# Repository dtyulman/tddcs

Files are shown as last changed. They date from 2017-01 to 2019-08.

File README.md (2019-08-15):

# Time-domain diffuse correlation spectroscopy (TD-DCS)

Danil Tyulmankov, MIT M.Eng. Thesis

Code for analysis and modeling, and Latex source.

Thesis: 
https://dspace.mit.edu/handle/1721.1/113444

Associated publications: 
1) https://doi.org/10.1364/OPTICA.3.001006
2) https://doi.org/10.1364/OL.43.002756

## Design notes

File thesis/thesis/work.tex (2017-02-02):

%% !TeX root = work.tex
%\documentclass[thesis.tex]{subfiles}
%\usepackage{xr-hyper} 
%\externaldocument{intro}
%\begin{document}

\chapter{Completed Work} \label{sec:Chapter2}

Having set the theoretical ground for time-domain diffuse correlation spectroscopy and alluded to some of the instrumentation, as well as experimental and computational techniques involved in estimating optical and dynamical properties of turbid media, we now discuss in detail the prototype construction, the initial measurements, and theoretical modeling that was done over the course of this project. These are clearly only the first steps and there is much more development to be done and theory to be explored. 

\section{Instrument prototype construction} \label{sec:prototype_construction}
The primary challenge in meeting the conflicting narrow-pulse-width and long-coherence requirements of TD-DCS is in constructing the laser source and detector hardware. A practical requirement for making measurements is to have a high photon flux, so a custom source laser with high peak power must be designed, and sensitive time-correlated single photon counting detectors must be used. 

The final system design is shown in \autoref{fig:TD-DCS_instrument}. For this thesis work, only a subset of the system was implemented to demonstrate proof-of-concept, which we refer to as "first generation," and used for initial measurements. The "second generation" system was used in subsequent data collection for the theoretical discussion in \autoref{sec:theory}.

\subsubsection{First generation}
The source laser is a distributed Bragg reflector (DBR) laser (PH852DBR280TS, Photodigm, Inc.), with nominal light wavelength of 852 nanometers, continuous-wave coherence of 10 meters and 180 milliwatt average optical power (480 mW peak power). The pulses are created by electrically gain-switching the seed laser using a commercial picosecond pulsed laser driver (T165-9, Highland Technology, Inc.). Although the maximum repetition rate at which the TPSFs (4-5 ns long) from consecutive pulses will not overlap is 200MHz, the pulse board repetition rate is variable and we used it at no more that 150MHz. The pulse board also specifies that it is possible to vary the pulse width by injecting current pulses of varying width into the laser, but we found that the pulse width could not be increased beyond 100ps without corrupting the pulse shape, likely due to the physical limitations of the laser. 

\begin{figure}[tb]
    \begin{subfigure}[t]{0.49\textwidth}
        \centering
        \raisebox{0.75in}{}
        \caption{}
        \label{fig:laser_package}
    \end{subfigure}~%
    \begin{subfigure}[t]{0.49\textwidth}
        \centering
        
        \caption{}
        \label{fig:pulse_board}
    \end{subfigure}
    \caption{(a) Photodigm Mercury TOSA package (b) Highland T165 pulse board with connected Type-1 butterfly-packaged laser.}
\end{figure}

The primary challenge here is controlling the laser with the pulse board. The laser comes in a Mercury TOSA package (\autoref{fig:laser_package}) where due to the length of the ribbon cable, there is an excess parasitic inductance. While this is not an issue in the CW operation for which it was designed, for our pulsed operation the cable must be removed and the laser pins connected directly to the pulse board. Furthermore, the pulse board connector is designed with a pin socket connection for a Type-1 butterfly-packaged
laser diode (\autoref{fig:pulse_board}) that is incompatible with our laser. As such, the pin sockets must be removed and the laser pins soldered directly to the copper pads to which the pin sockets were attached. To account for the mismatch in pin spacing as shown in \autoref{fig:laser_board}, the gap is simply filled with solder -- an inelegant but effective solution.
%\TODO{controlling the pulse board}

\begin{figure}[tb]
    \begin{subfigure}{0.49\textwidth}
        \centering
        
    \end{subfigure}~%
    \begin{subfigure}{0.49\textwidth}
        \centering
        
    \end{subfigure}
    \caption{SolidWorks model of the laser and pulse board connection. Copper pads represent electronic connections to the pulse board. For both the board and the laser, the cathode is shown in red and the anode in blue. Original files can be found at \coderepolink}
    \label{fig:laser_board}
\end{figure}

The second challenge in the construction of the custom system is effectively coupling the light into the medium. The laser is mounted onto a custom machined aluminum frame as shown in \autoref{fig:laser_assembly}. The frame serves both as a heatsink and as an adapter for off-the shelf hardware used to for further shaping the laser beam. First, to avoid backreflections that may damage the laser, it is necessary to install an optical isolator at the output of the laser. For the 852nm wavelength of our laser, we used Thorlabs model IO-3D-850-VLP. To accurately position the isolator into the beam's path we mounted the isolator onto a Cage XY Translator (Thorlabs CXY-1) which was centered on the custom laser frame using 6mm diameter aluminum rods (Thorlabs ER4) as shown. Finally, to couple the light into an optical fiber for delivery into the medium, we used an adjustable FiberPort (Thorlabs PAF-X-15-PC-B). To mount the FiberPort onto our cage setup we used another XY translator which we modified with four screw holes to attach the FiberPort directly to the translating component. The FiberPort then offers an FC connection to an optical fiber. For our experiments, as with DCS, light is delivered to the medium using a multimode fiber. %, in our case 62.5 micron graded-index Thorlabs model \TODO{find model}.  

\begin{figure}[tb]
    \begin{subfigure}{0.49\textwidth}
        \centering
        
    \end{subfigure}~%
    \begin{subfigure}{0.49\textwidth}
        \centering
        
    \end{subfigure}
    \caption{SolidWorks model of the custom pulsed laser assembly. In the final construction, the assembly is bolted to a monolithic heatsink (not shown). Original files can be found at \coderepolink}
    \label{fig:laser_assembly}
\end{figure}

On the detection side, as with the other photon correlation techniques, to maximize $\beta$ and therefore the SNR, we would like to limit the detection area to a single speckle. In practice, this is not achievable so, as with DCS \cite[Section 6.2]{Boas1996thesis}, we instead use a single-mode fiber to collect scattered light from the medium and deliver it to the detector. For our experiments, 5.6 micrometer single-mode silica fibers are used. The detector is a novel red-enhanced, single-photon avalanche diode detector (SPAD), with a high temporal resolution, from the SPADlab at the Politecnico de Milano \cite{Gulinatti2012,Giudice2012}. 

Although a custom time-to-digital converter (TDC) card is included in the final design, for the first-generation prototype we use an off-the-shelf Becker \& Hickl GmbH SPC\=/600 \cite{Becker2014} card to record the micro and macro photon arrival times. Although it was originally designed for fluorescence correlation spectroscopy \cite{Becker2005, Becker2014}, the data collection technique is identical\footnote{The signal for FCS, of course, is different -- the source of light is fluorescent markers on molecules}. The photon arrival data was then exported from the Becker \& Hickl software for offline data analysis (\autoref{sec:analysis}).

\subsubsection{Second generation}
Since the construction of the original prototype, the second-stage amplification was added to the laser source using a pumped taper diode amplifier (m2k-TA-0850-3000-DHP, m2k-laser GmbH), allowing much higher peak power to be used in experiments \cite{Kangara2014,Poelker1995}. Furthermore, the development of the custom data acquisition hardware was completed, incorporating the time-to-digital converter (TDC) card with the custom FPGA firmware to measure photon timing, and a USB3 interface (Cypress EZ-USB FX3) to transfer photon data to the computer. Furthermore, an alternative pulsed laser source was acquired (PicoQuant CPDL-S-760) with a nominal wavelength of 760nm, used in the experiments for \autoref{sec:theory}.

\begin{figure}[tb]
    \centering
    
    \caption{Schematic of the TD-DCS instrumentation. Reprinted from \cite{Sutin2016}.}
    \label{fig:TD-DCS_instrument}
\end{figure}

\section{Data analysis methods} \label{sec:analysis}

\subsection{Computing the temporal point spread function}

As discussed in the previous section, we use time-correlated single photon counting methods to record the \emph{micro} and \emph{macro} times of the photons. To compute the TPSF, we can use the exact approach discussed in \autoref{sec:TD-NIRS} and simply histogram the micro times (i.e. time-of-flight) for many photons to estimate the distribution of intensity over time. There are, however, several instrumentation-specific considerations to be addressed.

\subsubsection{Reversed start-stop}
Many TCSPC modules, including the Becker \& Hickl SPC\=/600 and our custom time-to-digital converter, operate in what is known as "reversed start-stop" mode. In this setup, rather than recording the time starting at the generation of the input laser pulse and stopping at the arrival of a photon, the "stopwatch" starts running at the arrival time of a photon, and stops at the generation of the next laser pulse. The advantage of this method is that since photons are typically detected at a much lower rate than the input pulse train (i.e. there is less than one photon detected on average from each laser pulse), we only need to operate the hardware at the photon detection rate, rather than the much higher laser pulse rate \cite{Becker2014}. This is easy to compensate for by simply reversing the time axis of the histogrammed TPSF. 

\subsubsection{Folding}
When recording signals with very high repetition rates it may be necessary to record the TPSF over several periods of the pulsed laser. That is, instead of using every laser pulse as the time-of-flight reference, we might use every other one, or every fourth, and so on. The Becker \& Hickl SPC\=/600 card allows frequency division values of $d = 1,2,4,8, \textnormal{or } 16$. Of course, we can only work with a single TPSF. One option is to pick one period of the recorded histogram and delete all of the other photons. This is clearly unfavorable since we are only using $1/d$ of the recorded photons for analysis and thus unnecessarily reducing the signal-to-noise ratio. A much better approach is to fold all of the histograms onto one, as shown in \autoref{fig:tpsf_folding}

\begin{figure}[tb]
    \centering
    \begin{subfigure}{\textwidth}
        
    \end{subfigure}    
    \begin{subfigure}{\textwidth}
        
    \end{subfigure}
    \caption{TPSF folding. Top plot shows an example of a time-of-flight histogram collected using a Becker \& Hickl SPC\=/600 card with the frequency divider set to 8 (the eighth peak is out of range and therefore not recorded). Bottom left shows all the individual peaks shifted to line up with the first (each peak shown in its own color). Bottom right shows the sum of all the peaks to create the final TPSF (note the decrease in noise and the y-scale).}
    \label{fig:tpsf_folding}
\end{figure}

We would like to simply shift the $k$\textsuperscript{th} additional "sub-TPSF" to the left by $kT$ where $T$ is the time between two consecutive pulses. In reality, however, the micro time is discretized: in \autoref{fig:tpsf_folding}, for instance, we have 4096 discrete time bins spanning 50ns. Since the repetition rate of the laser $T$ (e.g. $\frac{1}{100\textnormal{MHz}}$) is typically not an integer multiple of the time resolution of the micro time (e.g. $\frac{50\textnormal{ns}}{4096}$), a more careful folding procedure is necessary. We compute the autocorrelation function of the raw histogrammed signal. The peaks in the autocorrelation function then will correspond to the lags of the raw signal for which it is most similar with itself. Since all of the TPSFs in the raw signal should be identical, the lag values for the autocorrelation peaks are the precise values by which we should shift each "sub-TPSF" for the best overlap with the first "sub-TPSF." We can then subtract the shifts from the raw stored micro times accordingly. The implementation to perform the folding directly on the TPSF is provided in \autoref{code:fold_tpsf} and on the raw micro times in \autoref{code:fold_micro}.

\subsection{Estimating $\mu_a$ and $\mu_s'$} \label{sec:est_opt_params}
One of the advantages of TD-DCS is the capability of estimating the tissue optical parameters concurrently with the measurements of the dynamical properties. Having computed the temporal point spread function as in the previous section, we can then analyze it using all of the computational tools developed for TD-NIRS \cite{Torricelli2014}. Although this aspect is outside of the scope of this thesis, we include a brief discussion for completeness. 

As mentioned in \autoref{sec:TD-NIRS}, the measured TPSF is actually not the true impulse response of the system. It is a convolution of the pathlength distribution function of the medium (i.e. the "true" impulse response of the medium) with the impulse response function (IRF) of the laser source and detection system. The resulting measured TPSF is therefore a broadened version of the true TPSF. In TD-NIRS, the laser pulses are a few picoseconds wide, and compared to the width of the "true" TPSF are negligible, so it is valid to ignore the broadening effects due to the instrumentation. Thus, we can directly fit the measured TPSF to estimate $\mu_a$ and $\mu_s'$. However, due to the coherence length requirements of DCS, we must use wider pulses that are hundreds of picoseconds and are no longer negligible compared to the width of the "true" TPSF, so fitting the measured TPSF directly will result in an error that is an increasing function of the pulse width. 

To compensate for this broadening, there are several deconvolution algorithms that attempt to remove the broadening effects of the instrumentation IRF. Deconvolution, however, is in general an ill-posed inverse problem that does not have a unique solution. Solving ill-posed problems can be considered an entire field in itself, and we do not discuss it further. See \cite[ch. 20]{Handbook} for discussion of this issue in the context of TD-NIRS. An alternative approach may be to pre-convolve the theoretical TPSF with the measured IRF before fitting. In this approach, rather than attempting to remove the effects of the IRF from the measured TPSF, we are fitting to the data a function that already has the IRF factored into it. 

\subsection{Computing the autocorrelation function} \label{sec:acf_comp}
As discussed in \autoref{sec:Coherent}, to estimate the dynamic properties of the medium, we measure the time-averaged autocorrelation function of the scattered light intensity $g_2(\tau) = \frac{\expval{I(0)I(\tau)}} {\expval{I(0)}}$ and find the parameters of the appropriate model to best fit the measured data. In this section we discuss the algorithms to compute this function from the photon-counting data. Since the intensity autocorrelation is equal to the photon autocorrelation, we will use $I(t)$ to denote the photon stream.

\subsubsection{Direct summation}
In general, by definition, the autocorrelation function $R(\cdot)$ of an arbitrary discrete-time signal $f(\cdot)$ is given by the convolution
\begin{equation} \label{eq:acor_def}
R(\tau) = (f*\bar{f})(\tau) 
        \equiv \sum_{t\in\mathbb{Z}}f(t)\bar{f}(t-\tau) 
        = \sum_{t\in\mathbb{Z}}f(t)f(t+\tau) 
\end{equation}
where $\bar{f}(t) = f(-t)$.

Using this definition, given the intensity of the photon stream as a function of time, we can directly evaluate this sum for every value of $\tau$. This procedure, however, is time-consuming since only the photon arrival times are recorded and therefore must be converted to a temporal-raster form. For a measurement $L$ seconds long at a sampling frequency $\omega_s$, this is a vector of length $T = L\omega_s$, containing a 1 if a photon arrived within that time bin and 0 otherwise, (e.g. if the vector of photon "macro" times is $\vb{m} = (1,4,5,7)$, then $I(t) = (1,0,0,1,1,0,1)$, see \autoref{code:times_to_bins}). 

Since $I$ is a finite-length vector (or alternatively, we can consider it to be a discrete-time function that is equal to zero outside of the interval $[0,T]$), it only makes sense to compute $R(\tau)$ for $\tau \leq T$, since $R(\tau) = 0$ for $\tau > T$. Furthermore, we are not interested in lags beyond which the signal has fully decorrelated, so we only need to consider $\tau \leq \tau_{max}$. In our application, $\tau_{max} << T$. Thus, the computational complexity of this algorithm is $\Theta(T\cdot\tau_{max})$ since we are summing $T$ terms $\tau_{max}$ times. 

Finally, note that computing the autocorrelation of the intensity $I(t)$ according to \autoref{eq:acor_def} results in the \emph{unnormalized} autocorrelation $G_2(\tau)$. Normalizing, we get 
\begin{equation}
g_2(\tau) = \frac{T}{N^2}G_2(\tau) 
\end{equation}
where $N$ is the total number of photons collected and $T$ is the number of time bins as defined above, so $G_2(0) = \frac{N^2}{T}$

\subsubsection{Fast Fourier transform}
Since the convolution of two signals in the time-domain is equivalent to their multiplication in the Fourier domain \cite{OW1997}, given an arbitrary function $f(t)$ we can instead compute $F(k)$, its discrete Fourier transform (DFT) (note that this is the discrete analog of \autoref{eq:fourier})
\begin{equation}
F(k) = \mathcal{F}\{f\} \equiv \sum_{t=0}^{T-1}f(t)e^{-\frac{2\pi j kt}{T}}, ~k\in\mathbb{Z}
\end{equation}
and compute the autocorrelation by
\begin{equation} \label{eq:acor_fft}
R(\tau) = \mathcal{F}^{-1}\left\lbrace \mathcal{F}\{f\} \cdot \mathcal{F}\{\bar{f}\} \right\rbrace
\end{equation}
where the inverse DFT is given by
\begin{equation}
\mathcal{F}^{-1} \{F\} \equiv \sum_{t=0}^{T-1}F(k)e^{+\frac{2\pi j kt}{T}}, ~k\in\mathbb{Z}
\end{equation}

The fast Fourier transform (FFT) algorithm allows us to compute the DFT as well as the inverse DFT with computational complexity $\Theta(T\log T)$. The element-wise multiplication in the Fourier domain takes $\Theta(T)$ time, so the entire algorithm has computational complexity $\Theta(T\log T)$ \cite[ch. 30]{CLRS2009}. Note that this method does not allow us to specify the longest lag we are interested in $\tau_{max}$ and computes the autocorrelation for all of the values of $\tau$ such that $f(t)$ and $f(t+\tau)$ overlap. In other words, $\tau_{max}=T$. As before, letting $f(t)=I(t)$ in \autoref{eq:acor_fft} gives us $G_2(\tau)$ so to compute $g_2(\tau)$ normalization is done as in the previous section. 

\subsubsection{Histogrammed interarrival times}
A much faster method for our application operates directly on the photon arrival times. To see the equivalence of this method with the direct summation method described above, consider \autoref{eq:acor_def}. First, observe that in our application, $f(t) = 0~\textnormal{or}~1~\forall t$, so if $R(\tau) = k$ for some $\tau$, then there were exactly $k$ pairs of photons arriving $\tau$ time steps apart. Therefore, for every value of $\tau$ we are interested in, we would like to count all pairs of photons that are $\tau$ time steps apart. The algorithm is outlined as follows.

Suppose we have recorded a length-$N$ vector $\vb{m}$ of photon arrival times (i.e. "macro" times). We initialize a length-$\tau_{max}$ array of zeros $R$ that we will use to histogram the interarrival times of the photon pairs.

The $i^{th}$ iteration of the algorithm considers entry $m_i$ in $\vb{m}$ as the first photon of a pair. It then, one by one, looks at all the subsequent photons $m_j,~(j>i)$ and calculates $m_j-m_i$, the interarrival time of the photon pair. Suppose $m_j-m_i=\tau$, so we increment $R(\tau) \leftarrow R(\tau) + 1$. Once we reach an entry $m_{j^*}$ such that $m_{j^*}-m_i>\tau_{max}$, we stop this iteration since $\vb{m}$ is a strictly increasing sequence and we know $m_{k}-m_i>\tau_{max}$ for all $k>j^*$. We increment $i$ and begin the next iteration. We iterate until $i = N$ and all the photon pairs that are less than $\tau_{max}$ seconds apart have been considered.

%% Although this works (and might be more intuitive) this is not quite right and is actually slower since we're performing unnecessary computations and discarding values %%
%For a length-$N$ vector $\vb{m}$ of photon arrival times (i.e. "macro" times), we begin by computing the first difference $\vb{m^{(1)}}$, i.e. $m^{(1)}_i=m_{i+1}-m_i$. Note that since $\vb{m}$ is strictly increasing, all entries in $\vb{m^{(1)}}$ are positive. Next, we histogram the entries in $\vb{m^{(1)}}$ into the vector $R$ so that $R(\tau)$ contains the number of occurrences of $\tau$ in $\vb{m^{(1)}}$, in other words, the number of \emph{consecutive} photons in $\vb{m}$ that are $\tau$ apart. Since we are not concerned with lags greater than $\tau_{max}$, discard all entries $m^{(1)}_i > \tau_{max}$. 
%
%There might, however, exist non-consecutive photons that are $\tau$ apart (e.g. if $\vb{m} = (1,4,5,7)$, the first and second entries are $\tau=3$ time steps apart, as well as the second and fourth). So, we next compute the difference in arrival times of every other photon $\vb{m^{(2)}}$, i.e. $m^{(2)}_i=m_{i+2}-m_i$. Histogram and add these values into $R$, so that $R(\tau)$ now contains the number of occurrences of $\tau$ in both $\vb{m^{(1)}}$ and in $\vb{m^{(2)}}$. Again, discard all entries $m^{(2)}_i > \tau_{max}$. Continue this procedure until $m^{(k)}_i > \tau_{max}~\forall i$.

If we were interested in computing the longest possible lag (i.e. $\tau_{max} = T$), we would have to consider all pairs of photons, so the worst-case computational complexity is $O(N^2)$. Note that this is a function of the number of photons $N$, rather than the time of the experiment $T$. Since we are only interested in lags $\tau \leq \tau_{max}$, the complexity is actually much better since each iteration only looks at photons that arrived less than $\tau_{max}$ seconds after the one under consideration for that iteration. If the average flux is $\phi$ photons per time step, the expected number of pairs of photons considered in each iteration is $\phi\tau_{max}$ (note $\phi T=N$). Therefore, in expectation the runtime is $\Theta(N\cdot\phi\tau_{max})$

What we have computed in the vector $R$ is, in fact, the unnormalized measured intensity autocorrelation function $G_2(\tau)$. Once again, we normalize these values as before to compute $g_2(\tau)$. See \autoref{code:acorr_times} for an implementation of this algorithm. 

\subsubsection{Progressive binning/Multiple tau} 
For completeness, we include an alternative fast method for computing the autocorrelation function, as used in the Becker \& Hickl photon counting software, \cite{Becker2014} as it is representative of the ideas used in many of the current digital correlators. 

We begin by computing the autocorrelation as in \ref{eq:acor_def}. In other words,  after converting the photon arrival times to the temporal-raster form, we shift our signal to get $I(t+\tau)$, element-wise multiply $I(t)$ and $I(t+\tau)$, and sum all the values in the resulting vector. After $k_\tau$ shifts (where $k_\tau$ is a user-defined parameter), we re-bin the photon-arrival raster by a factor of three: for every three time bins of length $l$ we replace it with a single time bin of length $3l$, and if a photon arrived in any of the three original time bins, the new bin contains a 1 and 0 otherwise.  We then compute the autocorrelation on the re-binned signal as described. We continue this process (\autoref{fig:prog_bin}) until we reach the desired number of lags. 

\begin{figure}[tb]
    \centering
    
    \caption{Autocorrelation with progressive binning. Reprinted from \cite[p.~461]{Becker2014}}
    \label{fig:prog_bin}
\end{figure}

Note that due to the repeated re-binning of the photon stream, this procedure only calculates an estimate of the autocorrelation function, thus there is a trade-off between runtime and accuracy \cite{Magatti2001}. 

To reduce noise, although we perform the autocorrelation using the histogramming method described above, for display purposes we re-bin the results to look like the results produced by a multi-tau algorithm (\autoref{fig:rebinned_example}). Observe that with longer lag times, there are fewer photons contributing to the autocorrelation so the noise increases. Thus, it makes sense to smooth the autocorrelation function by an increasingly wider window. See \autoref{code:rebin_to_multitau} for an implementation.

\begin{figure}[tb]

\centering
\caption{Exact autocorrelation computed by histogramming interarrival times and re-binned with progressively larger bins $(k_\tau=30)$ for visualization. (Note that the peak at the smallest lags is an artifact due to the detection hardware. Since unpolarized light was used here, the maximum value for $\beta$ is 0.5)}
\label{fig:rebinned_example}
\end{figure}

\subsection{Estimating $\beta$ and BFi} \label{sec:fit_beta_bfi}
Having computed the measured autocorrelation function as in the previous section, we can attempt to estimate the model parameters of interest. Although we can estimate $\mu_a$ and $\mu_s'$ by fitting the theoretical TPSF to the measured data as is done in practice for TD-NIRS (\autoref{sec:TD-NIRS} or \autoref{sec:est_opt_params}), for reliability in these experiements, we measure the optical properties of the medium independently using a commercial FD-NIRS instrument \cite{MetaOx}.

Since in our experimental setup the source-detector separation is sufficiently small compared to the depth and surface area of the phantom, we estimate it as a semi-infinite medium. The theoretical DCS autocorrelation function for a semi-infinite medium in a reflectance setup is given by \autoref{eq:g1_DCS_seminf}. We use the Levenberg-Marquardt algorithm \cite{More1978}, a common nonlinear least squares fitting procedure, to find the blood flow index (BFi, given by $\alpha D$ in \autoref{eq:g1_DCS_seminf}) parameter which results in the closest match between the data and the theoretical form. 

Since what we have measured, however, is the intensity autocorrelation function $g_2$, related to $g_1$ through \autoref{eq:siegert}, there is another unknown parameter $\beta$ that needs to be estimated. Since $\beta$ depends on the spatial and temporal coherence properties of the light in the experimental setup, it is practical to directly fit this value simultaneously with the BFi.

It is also important to note, however, that due to artifacts such as afterpulsing which arise from feedback in the detector hardware \cite{Zhao2003}, the autocorrelation values for the smallest values of $\tau$ is not valid and should be ignored for the purposes of fitting. As shown in \autoref{fig:acf_fit_example}, only a subset of the measured autocorrelation curve is used for the fitting procedure. The range for fitting is chosen visually, although the typical minimum lag used is around $10^{-5}$ seconds. The implementation for estimating the parameters is given in \autoref{code:dcs_fit}, using the $g_2(\tau)$ function defined in \autoref{code:g2}.

\begin{figure}[tb]
    \centering
      
    \caption{The computed autocorrelation function and the best model that fits the data. Short lags are invalid and are ignored for the purpose of fitting the data.}
    \label{fig:acf_fit_example}  
\end{figure}

\subsection{Time-gating the photons} \label{sec:time-gate}
We now reach the essential aspect of time-domain diffuse correlation spectroscopy -- time-gating the photons and thus measuring the autocorrelation using a subset of photons that traveled a fixed pathlength through the medium. Since measurements are performed in the reflectance geometry (\autoref{fig:reflectance}), short pathlengths correspond to photons in the superficial layers, and long pathlengths to photons in the deeper layers. Thus, in the neuromonitoring setting, if we compute the autocorrelation of "deep" photons, we can measure the cortical blood flow avoiding the confounds from the superficial layers. 

Since we have the recording of the full photon stream with micro and macro times for each photon, we can simply select the photons whose micro times correspond to the portion of the TPSF we wish to analyze. Having selected the photons with micro times within a specified range, we then compute the autocorrelation using only that subset of photons. We then fit that autocorrelation using the appropriate model as described in the previous section to estimate the BFi in the corresponding layer of the medium.

\section{Results}
In this section, we discuss the three primary experiments conducted for validation of various aspects of the TD-DCS technique. All of the measurements are conducted using "phantoms" -- artificial objects designed to mimic biological samples for the purposes of device testing. Milk is a common choice for phantoms for diffuse near-infrared biomedical optical devices, due to its high scattering and low absorption coefficients resembling biological tissue, as well as its low price and easy availability. Liquid silicone as well as a polystyrene microsphere solution were also used for other phantoms, described in detail in the following subsections.  

\subsection{Initial measurements}

For the initial test of TD-DCS using the first-generation system, we measured the flow properties for four different dilutions of whole milk with water (1:0, 1:1, 1:2, and 1:3 milk-to-water ratios), as well as for a solution of polystyrene microspheres (1.73\textmu m diameter, 0.0013\textmu m\textsuperscript{-1} concentration, 1.55 refractive index). Due to the fat content in milk, its flow properties are temperature dependent and to normalize for this each of the five solutions was brought to room temperature (24\textdegree C). Due to the low average power of the pulsed laser without the amplifier %({\color{red} [TODO peak, average]}),
to optimize the measured light intensity the measurement was made in a standard $12.5\times 12.5\times 45$~mm cuvette in the transmission geometry. %For each measurement, approximately {\color{red} [TODO photons]} were collected over {\color{red} [TODO seconds]}. 
At $\lambda=850$nm, the scattering coefficient for whole milk was assumed to be $\mu_s'=26 \textnormal{cm}^{-1}$, and proportional to the concentration (i.e. $\mu_s'=13 \textnormal{cm}^{-1}$ for a 1:1 dilution, $\mu_s'=8.67 \textnormal{cm}^{-1}$ for 1:2, $\mu_s'=6.5 \textnormal{cm}^{-1}$ for 1:3). The scattering coefficient for the microspheres is calculated using Mie theory \cite{MieCalc} to be $\mu_s'=4.9 \textnormal{cm}^{-1}$. The absorption coefficient in all five samples was assumed to be equal to water, $\mu_a'=0.042 \textnormal{cm}^{-1}$.

Each measurement was taken three times, both with the first-generation TD-DCS system and with a CW-DCS system for comparison. The results are summarized in \autoref{fig:init_meas_bfi}. The average values are reported, the error bars represent one standard deviation. As evident in the figure, the time-domain measurements systematically overestimate BFi (in this case it is equivalent to the Brownian diffusion coefficient $D_B$). This is, in fact, contradictory to the results previously seen in the context of varying the coherence length of the source. Bellini et. al., for example, show a slower decay rate for measurements using short-coherence light in comparison to a coherent source \cite{Bellini1991}.

\begin{figure}[tb]
    \centering
    
    \caption{Initial BFi measurements using the first-generation TD-DCS system, in comparison with a state-of-the-art CW-DCS system. The average value over three separate measurements is shown, with error bars representing the standard deviation.}
    \label{fig:init_meas_bfi}
\end{figure}

\subsection{Two-layer phantom} \label{sec:two_layer}
To validate the depth-resolving capabilities of TD-DCS, we perform measurements in a simple two-layer phantom. The phantom consists of two immiscible liquids with varying viscosities held in a standard 500mL beaker. The bottom layer is a 1-to-3 dilution of whole milk and water as in the previous section, and the top layer is liquid silicone with added pigment to modify its scattering properties. As above, the absorption and scattering coefficients for diluted milk are $\mu_s'=6.5 \textnormal{cm}^{-1}$ and $\mu_a'=.042 \textnormal{cm}^{-1}$. For the liquid silicone $\mu_s'=3.7 \textnormal{cm}^{-1}$ and $\mu_a'=.035 \textnormal{cm}^{-1}$, measured using an FD-NIRS system \cite{MetaOx}.

Since the liquid silicone is qualitatively more viscous than diluted milk, we should expect that the BFi is lower in the top layer than the bottom layer. For the purposes of this analysis, all photons arriving prior to the peak of the TPSF are considered "early" and those arriving after the peak considered "late." We compute two autocorrelation functons, using "early" and "late" photons and fit them with a semi-infinite homogeneous model to get a first estimate on the BFi values. The results are shown in \autoref{fig:early_late} for a phantom with a 2.5mm thick layer of liquid silicon on the surface of the diluted milk. Although a semi-infinite model is not fully appropriate for this medium, as evidenced by the imperfect fit in the figure, we nevertheless see a 45\% increase in BFi from the more viscus top layer to the bottom layer.

\begin{figure}[tb]
    \centering
    
    \caption{Autocorrelation curves and the corresponding BFi estimates computed in a two-layer phantom using only the early photons or only the late photons. As expected, the BFi is smaller for early photons, corresponding to the more viscous top layer.}
    \label{fig:early_late}
\end{figure}

\subsection{Measured vs. theoretical values of $\beta$} \label{sec:theory}
In all of the theoretical derivations and models of autocorrelation functions thus far, we have implicitly assumed that the coherence time of the laser source is infinite. In the case of CW-DCS, this is typically valid, since the coherence time of a continuous wave laser can be on the order of 30 nanoseconds (which, in a vacuum, equates to a coherence length of 9 meters). In comparison to the time-of-flight of a photon through tissue, which is no more than several nanoseconds, this is a valid assumption. 

Not all laser sources, however, are that strongly coherent. In 1991 Bellini et. al. published a paper addressing the problem of making DLS and DWS measurements using a source with finite coherence length \cite{Bellini1991}. According to their model, assuming the spectrum of the laser source is Gaussian, the intensity autocorrelation function is given by
\begin{equation} \label{eq:g2_bellini}
g_2(\tau) = 1 + \int\limits_{0}^{\infty} \int\limits_{0}^{\infty} P(s)~P(s')~ g_1(s,\tau)~ g_1(s',\tau)~ e^{-2\left(\frac{s-s'}{l_c}\right)^2} ds~ds'
\end{equation}

Consider the photons traveling through the medium with a pathlength $s$ and the photons with pathlength $s'$. If the difference in pathlengths $s-s'$ is greater than the coherence length $l_c$ of the light, the phase of the photons is uncorrelated simply by virtue of the coherence of the light itself, irrespective of the loss of coherence caused by scattering from moving particles in the medium. As a result, the baseline measured intensity autocorrelation function at lags greater than the coherence time will be considerably smaller than it would for a coherent light source. Since the time resolution of a typical correlator is not high enough to detect this baseline drop in autocorrelation, it appears that $\beta$, i.e. the value of $g_2(\tau)$ with $\tau$ extrapolated to zero, is significantly lower than it would be for coherent light. Thus, the \emph{effective} $\beta$ depends not only on the detected coherence area as discussed in \autoref{sec:DLS}, but also on the temporal coherence of the source. 

As noted before (\autoref{sec:TD-DCS}), since we're using pulsed laser light, the temporal coherence length becomes upper bounded by the temporal width of the pulse. Thus, we can use \autoref{eq:g2_bellini} to model the intensity autocorrelation $g_2$ for varying coherence lengths, as shown in \autoref{fig:g2_bellini_example}. The code to run this simulation is provided in \autoref{code:g2_sim} Assuming the pulse is transform-limited, we simply set $l_c = v\Delta t$, where $\Delta t$ is the temporal width of the pulse and $v$ is the speed of light in the medium. Effectively, this models $g_2$ using all of the photons from the TPSF. We would also like to investigate from a theoretical standpoint the effects of time-gating the photons as in \autoref{sec:time-gate}.

\begin{figure}[tb]
    \centering
     
    \caption{Simulated $g_2(\tau)$ using \autoref{eq:g2_bellini}, varying source coherence, for a homogeneous semi-infinite medium with $g_1(s,\tau)$ given by \autoref{eq:g1_pathlength} and $P(s)$ given by normalizing \autoref{eq:TPSF}, $\mu_a=.05 \textnormal{cm}^{-1}$, $\mu_s'=1 \textnormal{cm}^{-1}$, $\lambda=800\textnormal{nm}$, $\rho=10 \textnormal{mm}$, $D_B=10^{-9} \textnormal{ cm}^2/\textnormal{s}$}
    \label{fig:g2_bellini_example}
\end{figure}

To model the time-gating, we simply replace $P(s)$ in \autoref{eq:g2_bellini} by $P'(s)$, a pathlength distribution that corresponds to the subset of pathlenths that are included in the time-gate, given by:
\begin{equation} \label{eq:modified_bellini_pdf}
P'(s) = \frac{P(s)~\textnormal{rect}(s; s_{min}, s_{max})}{\int\limits_{0}^{\infty} P(s)~\textnormal{rect}(s; s_{min}, s_{max}) ~ds}   
\end{equation}
where
\begin{equation}
\textnormal{rect}(s; s_{min}, s_{max}) = 
\begin{cases}
1,~s_{min} \leq s \leq s_{max} \\
0,~\textnormal{otherwise} \\
\end{cases}
\end{equation} 
is the rectangle, or boxcar, function that controls the limits of the time-gate by specifying the shortest and longest pathlengths to include in the gate, $s_{min}$ and $s_{max}$, respectively. The denominator is an normalization term to ensure that $P'(s)$ is a proper probability density function and integrates to $1$. 

\subsubsection{Varying gate width}
The time-gating procedure removes all photons outside the specified gate limits, so only photons whose pathlengths differ by no more than $s_{max}-s_{min}$ remain. Thus, we are computing the autocorrelation using photons which have similar pathlengths and thus have not lost their phase relationship simply by virtue of the finite coherence length. In the limiting case, if we consider only the photons which have a single pathlength $s=s_{min}=s_{max}$, the only contribution to their loss of coherence comes from interaction with the moving particles in the medium, and not from the coherence properties of the incident light\footnote{This is why the coherence requirements for DLS are not as strict as for DWS or DCS: since the light is scattered exactly once, there is only one pathlength to consider.}. Since coherence is not a binary phenomenon (\autoref{sec:fundamentals_coherence}), we would expect that wider time-gates would result in a lower value of $\beta$, with a maximum value of 0.5 (since we're using unpolarized light, c.f. \autoref{sec:DWS}) for an infinitely narrow gate as described above, and a minimum value equal to the CW value for an infinitely wide gate that considers all of the photons. 

To demonstrate this behavior, we record data from a simple semi-infinite phantom and analyze the data with varying widths of the time-gate. The measurements are made with the second-generation system with the secondary PicoQuant laser ($\lambda=760$nm), as described in \autoref{sec:prototype_construction}, using a 1-to-4 diluted whole milk phantom held in a standard 500mL beaker. A reflectance geometry was used with the source and detector fibers lowered directly onto the surface of the liquid at three source-detector separations (5, 10, 15mm). These distances are small compared to the surface area and depth of the medium, which is therefore modeled as semi-infinite. We then compute the autocorrelation using subsets of photons corresponding to gate widths increasing in 50ps increments and find the value of the effective $\beta$ for each one, following the analysis in \autoref{sec:fit_beta_bfi}. For the purpose of fitting in this experiment, the values of $\mu_a=0.51\textnormal{cm}^{-1}$ and $\mu_s'=5.67\textnormal{cm}^{-1}$ are obtained using a separate FD-NIRS system \cite{MetaOx}. The results for a 10mm separation are shown in \autoref{fig:beta_width_meas_10mm}. 

To compare the results of the measurement with the theoretical predictions, we vary the gate width in the simulated model of $g_2$ as described above, using theoretical models of $g_1$ and $P(s)$ for a semi-infinite homogeneous medium using the values of $\mu_a$, $\mu_s'$, $\rho$, and $\lambda$ prescribed by the experimental setup. Note that since we are only looking at the value of $\beta$, i.e. $g_2(\tau=0)$, the $D_B$ parameter is irrelevant since it only affects the decay rate of the function and not the intercept. We assume that the pulses (100ps full width at half-max) are transform-limited and therefore the coherence length $l_c = v \cdot [100\textnormal{ps}]$ where $v = \frac{c}{n}$ for the assumed refractive index of the medium $n=1.33$. As the computed $\beta$ values show in comparison with the measured values, this is likely to be an over-estimate. For perspective, we also calculate the values using an assumed coherence time of 10ps. The results for a 10mm separation are shown in \autoref{fig:beta_width_sim_10mm}. 

Although the simulations overestimate the absolute values of $\beta$, the simulated results shown a similar relative trend as the gate width increases, and a similar total drop in $\beta$ from the shortest to the longest gate.

\begin{sidewaysfigure}
    \begin{subfigure}{0.49\textwidth}
        \centering
        
        \caption{}
    \label{fig:beta_width_meas_10mm}
    \end{subfigure}~%
    \begin{subfigure}{0.49\textwidth}
        \centering
        
        \caption{}
        \label{fig:beta_width_sim_10mm}
    \end{subfigure}
    \caption{Effects of varying gate \emph{width} on $\beta$, derived from (a) measurements and (b) simulations. All gates start at the leftmost edge and continue rightwards until the respective colored edge. Values of $\beta$ are shown in corresponding colors. $\rho=10\textnormal{mm}$, $\mu_a=0.51\textnormal{cm}^{-1}$, $\mu_s'=5.67\textnormal{cm}^{-1}$.}
    \label{fig:beta_width_10mm}
\end{sidewaysfigure}

\subsubsection{Varying gate delay}
As has already been discussed, varying the delay of the time gate would give us the autocorrelation of subsets of photons which traveled different depths into the medium\footnote{This is not strictly true since it's possible that a photon took a long path and remained in the superficial layers. However, it is more likely that it, in fact, did reach a deeper layer than a photon with a short pathlength.}, which enables the estimation of dynamical properties at varying depths. In practice, we also observe that increasing the gate delay results in a decrease in $\beta$. 

To demonstrate this, we analyze the data from the semi-infinite homogeneous diluted milk phantom described above with a fixed 50ps gate width, and changing the gate delay in 50ps increments. An analogous simulation is performed for comparison. Results for the 10mm separation are shown in \autoref{fig:beta_delay_10mm}.

The limitations of this model are now more evident as fails to fully describe the observations. Notice that in the measured data, $\beta$ continues to decrease with increasing gate delay, whereas according to the simulation it plateaus beyond the initial drop. Also note the relative drop in $\beta$ for the simulation is extremely small, compared to the much more significant drop observed in the measurements. Furthermore, this cannot simply be explained by the coherence time of the laser, as evidenced by the points corresponding to the 10ps coherence time in the simulation, which exhibit a small initial drop and plateau.  

\begin{sidewaysfigure}
    \begin{subfigure}{0.49\textwidth}
        \centering
        
        \caption{}
        \label{fig:beta_delay_meas_10mm}
    \end{subfigure}~%
    \begin{subfigure}{0.49\textwidth}
        \centering
        
        \caption{}
        \label{fig:beta_delay_sim_10mm}
    \end{subfigure}
    \caption{Effects on $\beta$ of varying gate \emph{delay} from (a) measurements and (b) simulations. All gates are 50ps wide and are shown as colored bars. Values of $\beta$ are shown in corresponding colors. $\rho=10\textnormal{mm}$, $\mu_a=0.51\textnormal{cm}^{-1}$, $\mu_s'=5.67\textnormal{cm}^{-1}$.}
    \label{fig:beta_delay_10mm}
\end{sidewaysfigure}

%~\\ \TODO{include plots for measured/sim for 5,10,15mm at 10,40MHz in appendix}

\section{Conclusions and further work}
There are several further considerations to be addressed as immediate next steps after this work. When computing the depth-resolved flow values in \autoref{sec:two_layer}, we arbitrarily split the TPSF into "early" and "late" photons using the peak as the midpoint. An alternative might be to use the average time-of-flight, or the median. Furthermore, it is important to note that the correct location to split the TPSF will depend on the thickness of the top layer and is unlikely to be in the "middle" by any of these metrics. A first approach may be to exhaustively split the TPSF at every plausible location, and recompute both the "early" and "late" autocorrelation functions and choose the splitting point to be the one that gives results most closely resembling those for each of the homogeneous media separately.

It is also necessary to consider the correlation diffusion model itself. It may be more appropriate to use a slab to model the propagation of "early" photons through the top layer, and a two-layer semi-infinite medium for the "late" photons. Note that if the absorption and scattering coefficients differ in the two layers, when computing the autocorrelation fit in the bottom layer it may not be fully appropriate to simply use the optical properties of the bottom layer -- the photons reaching the bottom layer have already been scattered through the top layer and thus cannot be analyzed using the optical properties of the bottom layer alone. This question is further complicated for multi-layer models resembling biological systems of interest. The human head, for instance, has been modeled with up to 15 layers \cite{Steinbrink2001}.

Another thing to consider regarding the correlation diffusion model is that the solution for $G_1(\tau)$ (regardless of the geometry) assumes a continuous "source" of correlation that then diffuses and reaches a steady-state. For a continuous-wave light source, this model is intuitively satisfying since the light propagation also follows a steady-state diffusion solution. Further investigation into the validity of this assumption for a pulsed light source is necessary, as the correlation may in fact not diffuse according to a steady-state "correlation source" and there may be a drop in the autocorrelation function that is not accounted for by the finite coherence length model introduced by Bellini et. al. \cite{Bellini1991}. 

To model the effects of time-gating, we have modified the model from Bellini et. al. to instead consider subsets of the pathlength distribution. This model, however, does not fully account for our observations. To explain the mismatch between the predicted and measured values of $\beta$, there are not only theoretical developments to consider but also practical. For instance, it may be necessary to look for artifacts in the laser pulse itself, as it may violate some of our assumptions. One such artifact is mode-hopping, where the laser switches longitudinal modes, resulting in discrete jumps in the wavelength \cite{Heumier1992} during operation. It is possible to address mode-hopping by operating at a lower power. Another is that the pulse may not be transform limited and the electric field may, for example, exhibit a "chirp" (i.e. the frequency of the electric field increases with time) during the pulse. In this case, transform limiting can be achieved by pulse compression. From a modeling perspective, if there is a chirp, the effective wavelength changes with varying gate delay, which is not considered for in the theoretical account given in \autoref{sec:theory}.

Intermodal dispersion in the optical fibers may be yet another source of error due to instrumentation. If there is more than one propagation mode in the fiber (i.e. a multimode fiber), there will be broadening of the pulse since some rays will travel a shorter path through the fiber than others. While it can be neglected in CW operation, this broadening can be on the order of tens of picoseconds per meter, a significant portion of the pulse width itself. The impacts of this effect have so far been ignored in the analysis but need to be addressed. It is possible to reduce modal dispersion using a graded-index (GI) fiber to a few picoseconds per meter, or eliminate it using a single-mode fiber at the expense of light intensity.

To conclude, these have been only the first steps in constructing a clinically viable time-domain diffuse correlation spectroscopy system. We have constructed a first prototype and successfully demonstrated the viability of the method with initial measurements that produce reasonable estimates of Brownian diffusion in a phantom, compared to the measurements made by CW-DCS. We furthermore showed proof-of-concept with depth-resolved measurements in a two-layer phantom. We finally discussed the limitations of the current theoretical developments, which only partially explain the observations made using TD-DCS measurements. Despite its early stages, this is undoubtedly an extremely promising technique for highly reliable measurements of blood flow and oxygenation, with a rich potential for biomedical optical imaging applications.

%\end{document}

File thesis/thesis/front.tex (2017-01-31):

%% !TeX root = front.tex
%\documentclass[thesis.tex]{subfiles}
%\begin{document}

\title{Time-domain diffuse correlation spectroscopy: instrument prototype, preliminary measurements, and theoretical modeling}
\author{Danil Tyulmankov}
\date{January 2016}

%\end{document}

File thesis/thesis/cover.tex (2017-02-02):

\def\signature#1#2{\par\noindent#1\dotfill\null\\*{\raggedleft #2\par}}

\newgeometry{margin=1in}

\begin{titlepage}   
{\Large\bf Time-domain diffuse correlation spectroscopy: instrument prototype, preliminary measurements, and theoretical modeling  \par}
by\par
{\Large  Danil Tyulmankov}
\par
S.B., EECS and BCS, MIT (2016)
\par
Submitted to the Department of Electrical Engineering and Computer Science \\
in partial fulfillment of the requirements for the degree of
\par
Master of Engineering in Electrical Engineering and Computer Science
\par
at the
\par
MASSACHUSETTS INSTITUTE OF TECHNOLOGY
\par
February 2017
\par
\copyright\ 2017 Danil Tyulmankov.  All rights reserved.
\par
The author hereby grants to MIT permission to reproduce and to distribute publicly paper and electronic copies of this thesis document in whole or in part in any medium now known or hereafter created.
\vskip 3\baselineskip
\signature{Author}{Department of Electrical Engineering and Computer Science \\ February 3, 2017}
\par
\signature{Certified by}{Maria Angela Franceschini \\ Associate Professor of Radiology, Harvard Medical School\\ Thesis Supervisor}
\par
\signature{Certified by}{Elfar Adalsteinsson \\ Professor of Electrical Engineering and Computer Science, MIT \\ Thesis Co-Supervisor}
\par
\signature{Accepted by}{Christopher Terman \\ Chairman, Masters of Engineering Thesis Committee}
\vfill
\end{titlepage}

\cleardoublepage
\begin{center}
{\large{\bf Time-domain diffuse correlation spectroscopy:\\ instrument prototype, preliminary measurements, and theoretical modeling} \\
by \\
Danil Tyulmankov\\[\baselineskip]}
\par

Submitted to the Department of Electrical Engineering and Computer Science \\
on February 3, 2017, in partial fulfillment of the \\
requirements for the degree of \\
Master of Engineering in Electrical Engineering and Computer Science
\end{center}
\par
\subsection*{Abstract}{
\addcontentsline{toc}{section}{Abstract}
Near-infrared spectroscopy (NIRS) is an emerging diffuse optical imaging tool with both clinical and academic applications such as functional brain imaging, breast cancer detection, and cerebral health monitoring. Due to its non-invasiveness, high spatial and temporal resolution, and portability, it has been rapidly growing in popularity over the last 40 years. The technique relies on near-infrared light to measure optical properties -- scattering and absorption -- which can then be used to infer details of the underlying tissue physiology. Diffuse correlation spectroscopy (DCS)  is a complimentary optical technique that relies on long-coherence laser light, also in the near-infrared range, to measure dynamical properties of a medium -- in the biomedical context, blood flow. While NIRS and DCS can be used in conjunction to provide even more powerful information, they require separate instrumentation, resulting in reduced portability and difficulty in bedside monitoring. In brain imaging applications, both NIRS and DCS suffer from confounds due to layers surrounding the brain, such as the scalp and skull. While this issue has been addressed in NIRS using time-resolved instrumentation known as time-domain (TD) NIRS, it has been largely ignored in the context of DCS. 

In this work, we demonstrate a novel time-domain diffuse correlation spectroscopy (TD-DCS) technique embodied in a single instrument capable of simultaneously measuring optical and dynamical properties. Along with maintaining portability, the instrument reduces error by directly measuring the absorption and scattering values necessary for precise flow estimation, and removes a major confounding factor by suppressing unwanted signal from superficial layers through time-gating. We describe the construction of the first instrument prototype and demonstrate the depth resolution proof-of-concept with measurements of multi-layer media. We further discuss the theoretical considerations of modeling the light interaction with tissue, necessary for reliable estimates.
\\
\\
Thesis Supervisor: Maria Angela Franceschini \\ 
Title: Associate Professor of Radiology, Harvard Medical School
\\
\\
Thesis Co-Supervisor: Elfar Adalsteinsson \\ 
Title: Professor of Electrical Engineering and Computer Science, MIT
}
\cleardoublepage

\section*{Preface and Acknowledgments}
\addcontentsline{toc}{section}{Preface and Acknowledgments}
\epigraph{\textit{"The more we learn about the world, and the deeper our learning, the more conscious, specific, and articulate will be our knowledge of what we do not know, our knowledge of our ignorance."}}{Karl Popper (1963)}

Despite the incredible amount I have learned in the last two years, I can make no claims about being an expert in this field. Although I now know far more than I did when I first discovered diffuse optics, even more so I have come to realize how much I have yet to learn. It is beyond the scope of this work to describe in detail all that we \emph{do} know about the field, so instead I write this to outline what there \emph{is} to know. A comprehensive yet basic introductory text is difficult to find, so in addition to serving as the capstone of my past two years of learning and research, I write this thesis in hopes that it might be a good first exposure for someone who is just entering the field of biomedical diffuse optics. In other words, I write this for myself, two years ago, and hope it will be useful for someone who finds themselves in a similar situation. For this reason, I exclude most of the mathematical rigor and derivations, providing only the necessary context and intuition to more easily parse the details provided in the references. In addition to the background necessary for my project, I make an attempt to provide a small amount of history, give a bird's-eye view of the field, and organize the various terminology.  

% probably not in this section but I want to draw a "family tree" of optical imaging techniques somewhere (or a chart delineating them. Axes, I think, could be principles (e.g. scattering/absorption/models used) techniques (e.g. instrumentation,analysis) and applications (e.g. NIRS for Hb measurement or non-biomed, DLS for particle sizing or flow measurement)

I have many people to thank for helping me get to where I am now. First and foremost, I want to thank Mari for giving me the opportunity to explore a field I knew nothing about, and for her patience, guidance, and unwavering support throughout all of the inevitable ups and downs of this project. I thank David Boas for his insights into the theory behind the techniques discussed in this thesis, and the invaluable feedback on the experiments. Thank you to Jason Sutin for his engineering expertise and meticulous supervision, without whom the construction of the prototype would have been impossible. Of course, thank you to the Optics Division, and the entirety of the MGH/HST Martinos Center, in particular to Bruce Rosen for sharing his wisdom in trying times.
 
Outside of the Martinos Center, I want to thank Alexander Friedman for his mentorship during my undergraduate years, for pushing me to my maximum potential and beyond, and for preparing me for my graduate work. I thank my academic advisor, Dennis Freeman, for his patience, encouragement, advice, and availability despite increasingly hefty responsibilities. Finally, I thank Anne Hunter, who was the first to welcome me to the EECS department during my transfer from UMass Amherst my freshman year: "I'm not making any promises, but so far everyone whom I have recommended has been accepted." Without her, I am convinced, Course 6 would have long ago collapsed into anarchy. 

\cleardoublepage

\addtocontents{toc}{\protect\thispagestyle{empty}}
\tableofcontents

\restoregeometry

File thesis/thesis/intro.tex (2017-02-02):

\chapter{Introduction and Background} \label{sec:Chapter1}

Since the late 19th century, when Santiago Ram{\'o}n y Cajal established the neuron doctrine -- the groundbreaking idea that the brain is made up of individual cells -- the field of neuroscience has grown at a rapid rate. Numerous techniques for monitoring the brain in both academic and clinical settings have been developed. Electroencephalography (EEG) or magnetoencephalography (MEG), for example, records the electric or magnetic fields resulting from activity of large groups of neurons. Functional magnetic resonance imaging (fMRI), measures a correlate of neural activity caused by the presence of oxygenated blood in the working area of the brain. The ideal neuroimaging technology would be portable, non-invasive, and have both high spatial and temporal resolution (\autoref{fig:time_space_resolution}). Diffuse optics, a field expanding at an exponential \cite{Boas2014} rate, provides us with the potential to meet many of these requirements.

Near-infrared spectroscopy (NIRS), as the name implies, uses near-infrared light to measure optical properties of a medium -- absorption and scattering. Given these optical properties, we can then infer the physical properties such as chromophore concentration, or even make spatial maps of the inhomogeneities present in the medium. In the neuroimaging context, this allows us to localize blood oxy- and deoxy-hemoglobin concentrations and thus quantify functional activity in the brain \cite{Boas2014, Scholkmann2014}. In the clinical setting it can be used for diagnostics such as breast cancer, heart disease, muscle pathophysiology, and many others \cite{Sakudo2016}.

Diffuse correlation spectroscopy (DCS) is a complementary technique that takes advantage of the coherence of light to measure dynamical\footnote{A note on language: it may be tempting to say "static" absorption and scattering properties in contrast with "dynamic" flow properties. In fact, absorption and scattering properties may vary with time (for example, as a result of changes in chromophore concentrations -- functional NIRS \cite{Boas2014, Scholkmann2014} takes advantage of this phenomenon to measure brain activity), so we refer to them as \emph{optical} properties to differentiate them from \emph{dynamical} (not "dynamic") flow properties} properties of a medium such as blood flow in tissue \cite{Durduran2014, Buckley2014}. Conditions such as cardiovascular disease, stroke, head trauma, peripheral arterial disease, and cancer can be related to abnormal blood flow, and thus DCS can provide information for disease diagnostics and treatment efficacy metrics.

The combination of these techniques provides us with even more powerful information. In particular, we need to know the optical properties to estimate dynamical properties. Using NIRS concurrently with DCS gives us directly measured optical properties in the subject, without having to resort to tabulated average values. Furthermore, if we combine DCS blood flow data with NIRS measurements of hemoglobin concentrations, we can then calculate the cerebral metabolic rate of oxygen consumption, which is a reliable measure of brain health \cite{Durduran2010, Lin2013}.

\begin{figure}[tb]
    \centering
    
    \caption{Comparison of spatial and temporal resolution of various neuroimaging techniques. Reprinted from \cite{Strangman2002}, with permission from Elsevier}
    \label{fig:time_space_resolution}
\end{figure}

In the neuromonitoring setting, however, both NIRS and DCS suffer from confounding effects of the layers surrounding the brain such as the skull and the scalp. It has been demonstrated that using time-domain techniques for near-infrared spectroscopy improves the measurement's sensitivity to the brain \cite{Selb2005}. In this work we explore how time-domain NIRS can be extended to DCS with the introduction of a novel technique termed \emph{time-domain diffuse correlation spectroscopy} (TD-DCS).

We begin Chapter 1 with a thorough summary of the developments in the field of diffuse optics. We introduce the physical principles of making measurements with near-infrared light as well as the experimental setup and analysis techniques used in the various implementations of this principle. The focus is on developing the concepts leveraged by TD-DCS. In Chapter 2, we outline the construction of the first prototype TD-DCS system and demonstrate proof-of-principle with measurements on artificial phantoms. We also explore the impact of coherence length on the measured DCS correlation function in the time domain. Understanding this is critical for the development of the right model for the TD-DCS correlation function to accurately estimate flow.

\section{Near-Infrared Spectroscopy (NIRS)} \label{sec:NIRS}
% other links:
% https://en.wikipedia.org/wiki/Functional_near-infrared_spectroscopy
% http://www.scholarpedia.org/article/Near_infrared_imaging

To set the ground for understanding the "time-domain" ideas behind time-domain diffuse correlation spectroscopy, we begin with a discussion of a related optical imaging technique known as near-infrared spectroscopy (NIRS). We discuss three of its variations -- continuous-wave, frequency-domain, and time-domain\footnote{In fact, frequency-domain and time-domain NIRS carry the same type of information, so in some literature they are together referred to as "time-resolved spectroscopy" (TRS) \cite{Scholkmann2013}. Other authors reserve the term TRS solely for time-domain NIRS \cite{Wolf2007}.}. As the name implies, the third lays the foundation for the "time-domain" aspects of TD-DCS.  

There is a multitude of spectroscopic techniques that rely on the scattering and absorption of light, with experimental work dating as early as the 19\textsuperscript{th} century. Biomedical applications using near-infrared (NIR) light, however, were limited to superficial layers of tissue until 1977, when Frans J{\"o}bsis discovered that it could also be used to probe thicker samples. He used NIRS to measure in vivo brain hemodynamics \cite{Jobsis1977}, thus spurring the recent 40 years of development in this field. (See \cite{Ferrari2012} for a more detailed account on the history of NIRS). In contrast to prior approaches, NIRS measures \emph{diffuse} light that has scattered many times and an individual photon trajectory is a random walk, so in bulk they are estimated by a diffusion equation. Thus, this technique is also often referred to as diffuse optical spectroscopy (DOS). 

The fundamental idea behind NIRS is quite straightforward: we shine light into the tissue, measure it after it passes through, and then use an appropriate model to interpret the difference between the incident and detected light. NIRS is typically divided into three categories based on the type of incident light used and on what is measured by the detector. See \autoref{fig:CW_FD_TD_comparison} for an illustration of these ideas. First, the most simple and inexpensive continuous-wave (CW) systems illuminate the tissue with a \emph{constant-amplitude continuous} light and simply use the light’s attenuation to measure absorption. Next, frequency-domain (FD) systems use \emph{amplitude-modulated continuous} light and measure not only attenuation but also phase shift (delay) to get information about both absorption and scattering properties. Finally, time-domain (TD) systems use extremely short (on the order of a few picoseconds) \emph{pulses} of light and measure the time-of-flight of individual photons to determine not only absorption and scattering but also the pathlength of the photon to provide depth resolution. 

\begin{figure}[tb]
\centering

\caption{Comparison of the three variants of NIRS, illustrating the type of light used to probe the tissue. Reprinted from \cite{Scholkmann2013}, with permission from Elsevier.}
\label{fig:CW_FD_TD_comparison}
\end{figure}

Independent of the type of incident light used, one can also set up various configurations of light sources and detectors to measure optical properties as a function of location. In principle, NIRS or DOS strictly refers to a point-measurement instrument with a single source location and one (or more) detectors. In contrast, diffuse optical imaging (DOI) \cite{Strangman2002}, otherwise referred to as near-infrared imaging (NIRI) or topography, \cite{Scholkmann2013} uses multiple source-detector pairs, or a single one used to measure multiple locations \cite[ch. 9.1.4]{Handbook}, to reconstruct 2D images of the tissue using optical properties as contrast. Finally, diffuse optical tomography (DOT) requires spatially overlapping measurements from multiple sources for 3D reconstructions \cite[ch. 2.4.2]{Madsen2013}. We use the NIRS terminology to distinguish these techniques from diffuse correlation spectroscopy (DCS), described in \autoref{sec:CW-DCS}. 

Additionally, for a given source-detector pair, we can also vary their placement relative to the measured medium. In the \emph{transmission} (or, \emph{transmittance}) geometry, the source and detector are placed on opposite surfaces, with the measured medium in the middle (\autoref{fig:transmission}). In the \emph{reflectance} (or, \emph{backscattering}) geometry, we place source and detector on the same surface, separated by a few centimeters (\autoref{fig:reflectance}). Since in many biomedical applications the samples such as the human head are too thick or opaque, we cannot measure the light passing through the medium in the transmittance geometry. In this case, we take advantage of the fact that tissue is highly scattering and light diffuses in all directions, therefore illuminating a detector arranged in the reflectance geometry. 

\begin{figure}[tb]
        \centering
    \begin{subfigure}{0.49\textwidth}
        \centering
        
        \caption{}
        \label{fig:transmission}
    \end{subfigure}~%
    \begin{subfigure}{0.49\textwidth}
        \centering
        
        \caption{}
        \label{fig:reflectance}
    \end{subfigure}  
    \caption{(a) Transmission geometry through an infinite homogeneous slab of thickness $L$. (b) Reflectance geometry in a semi-infinite homogeneous medium with a source-detector separation $\rho$.}
    \label{fig:geometry}
\end{figure}

We limit the discussion here to the basics of NIRS, and the concepts necessary for the development of the theory behind TD-DCS. The focus will be point-measurements, as the image reconstruction algorithms \cite{Oleary1996thesis} are beyond the scope of this work. There are also variations of each of these techniques, such as spatially resolved spectroscopy (SRS) \cite{Wolf2007}, \cite[ch. 2.4.2]{Madsen2013} which uses multiple source-detector separations for a point-measurement to get better estimates, or broadband diffuse optical spectroscopic imaging which uses the entire spectrum of light for measurements \cite[ch. 9]{Handbook}. The details of the many applications of the technique and interpretations of the data are also omitted. Finally, we mention that there exist many other biomedical optical techniques that take advantage the same scattering and absorption phenomena, although for different applications and go by different names such as reflectance spectroscopy \cite[ch. 6]{Handbook} or light scattering spectroscopy \cite[ch. 8]{Handbook}.
 
\subsection{Fundamentals: Light and Physiology} \label{sec:NIRS_fundamentals}
Before we begin the more detailed discussion of NIRS, we present the fundamental concepts about light that are central to the techniques presented here, as well as some facts about its interaction with tissue. 

\subsubsection{Light, Absorption, and Scattering}
It is well-known that light is an electromagnetic wave, the simplest of which is a monochromatic plane wave. For simplicity we ignore the spatial extent and polarization, and suffice with a one-dimensional scalar description given by%\footnote{Note the factor of $\frac{1}{2}$ in the second equality, due to the relation $\expval{E(t)} = \frac{1}{2}\Re{\tilde{E}\tilde{E}^*}$}
\begin{equation} \label{eq:plane_wave_cos}
E(x,t) = E_0\cos(kx - \omega t + \phi) = \Re{E_0e^{i(kx-\omega t+\phi)}} = \Re{\tilde{E}(x,t)}
\end{equation}
The second equality is given by using Euler's formula, where $\Re{\cdot}$ represents the real part. Normally, it is omitted from the notation is always understood to be implicit, so we simply refer to an electromagnetic wave by
\begin{equation}\label{eq:plane_wave}
\tilde{E}(x,t) = E_0e^{i(kx-\omega t+\phi)}
\end{equation}

In general, however, we cannot directly measure the electromagnetic field. Rather, all optical detectors, including our eyes, can only measure intensity, i.e. the average energy per unit area per unit time, which is related to the electric field by
\begin{equation} \label{eq:field_intensity}
I(x) = \frac{\expval{\abs{E(x,t)}^2}}{\eta} 
= \frac{\expval{\abs{\tilde{E}(x,t)}^2}}{2\eta} 
= \frac{\expval{\tilde{E}(x,t)\tilde{E}^*(x,t)}}{2\eta} 
= \frac{E_0^2}{2\eta}
\end{equation}
where $\eta = \sqrt{\mu/\epsilon}$ is the impedance (a constant resulting from the electric and magnetic properties of the medium), $E^*$ represents the complex conjugate and $\expval{\cdots}$ represents the time-average
\begin{equation}
\expval{f} = \lim\limits_{T\rightarrow\infty} \frac{1}{T} \int\limits_{-T/2}^{T/2} f(t)~dt
\end{equation}

Electromagnetic radiation, of course, has another well-known interpretation in terms of quantized particles called photons that when analyzed in bulk appear as an electromagnetic wave. So the monochromatic wave above can be interpreted as a stream of photons all of which have the same energy, frequency, momentum, and direction.

%Hecht pg67 Handbook Biomed Optics 6.2.2
When light impinges onto matter, it will either be absorbed or scattered. If a photon's energy matches the difference in energy levels of an atom, the photon will be absorbed and its energy will be dissipated, e.g. as heat. In bulk matter, this phenomenon can be quantified using the Beer-Lambert Law (otherwise called Beer-Lambert-Bouguer Law or simply Beer's Law):
\begin{equation} \label{eq:beer-lambert}
I(\lambda) = I_0(\lambda)e^{-\mu_a(\lambda) \rho}
\end{equation}
or in its canonical form:
\begin{equation}
A(\lambda) \equiv -\log\frac{I(\lambda)}{I_0(\lambda)} = \mu_a(\lambda)\rho
\end{equation}
where $I_0$ is the intensity of the light from the source, $I$ is the measured light intensity at the detector, $\rho$ is the source-detector separation, and $\mu_a(\lambda)$ is the absorption coefficient, which depends on the properties of the medium. The quantity $-\log\frac{I}{I_0}$ is defined as the optical density (OD) or attenuation\footnote{Also note the related quantity transmittance is defined as $T \equiv \frac{I}{I_0}$} (A). The law states that as light passes through the medium over a longer distance, the intensity drops exponentially. In a solution, the absorption coefficient is proportional to the concentrations of \emph{chromophores} (light-absorbing compounds)
\begin{equation} \label{eq:muA_sum_chromo}
\mu_a(\lambda) = \sum_i c_i \varepsilon_i(\lambda)
\end{equation}
where $c_i$ is the concentration of chromophore $i$ and $\varepsilon_i(\lambda)$ is the proportionality factor called the \emph{extinction coefficient} \cite[ch. 8.2.1]{Handbook}. Thus, the attenuation of a medium is proportional to both the distance the light travels, as well as the chromophore concentration. Note that this relation is explicitly written as a function of $\lambda$ (omitted henceforth for brevity) -- it is wavelength-dependent, since the extinction coefficient varies for different wavelengths. This relation only holds if the medium is non-scattering, the chromophores  are independent of each other, and the concentration is homogeneous along the light path. \cite[ch. 2]{Madsen2013}
% Beer-Lambert 
%http://chem.libretexts.org/Core/Physical_and_Theoretical_Chemistry/Spectroscopy/Electronic_Spectroscopy/Electronic_Spectroscopy_Basics/The_Beer-Lambert_Law
%http://www.pci.tu-bs.de/aggericke/PC4/Kap_I/beerslaw.html

% Hecht p86-92
If a photon's energy is not high enough to cause a transition to a higher energy state, the atom's electron cloud is nevertheless driven into oscillation. As an oscillating electric dipole, the atom will immediately re-radiate the photon with the same amount of energy and wavelength, in a random direction. This is known as elastic scattering and will be the primary scattering mechanism at work in our discussion. As scattering depends not only on the individual atoms but also on the structure of the molecule, as well as the spacing and interactions of molecules in the medium, there are multiple models of scattering applicable for different scenarios.  Rayleigh scattering describes independent particles smaller than a wavelength of light arranged randomly in space. Mie scattering deals with particles larger than a wavelength. Inelastic scattering, in contrast, does not preserve the wavelength of the photon. Raman scattering is an example of this phenomenon.
% Rayleigh, Mie scattering
%http://hyperphysics.phy-astr.gsu.edu/hbase/atmos/blusky.html#c2

\subsubsection{Tissue optical properties}
% Handbook Bm Optics Ch 5
Light is absorbed and scattered by matter, and human tissue is no exception. Although we may seem opaque to visible light at first glance, a simple demonstration will indicate otherwise. If one covers a bright flashlight with his hand, the tissue will faintly glow red. As the incident light from the flashlight is white and contains all visible wavelengths, we see that red (and, in fact, infrared) light is least absorbed by tissue. We also see that the light exiting the tissue no longer resembles the rays of the incident light as it has also been scattered many times and is considered \emph{diffuse}. As we discuss in the next section, the photons can therefore be modeled as undergoing a diffusion process through the medium.

The primary optical absorbers (chromophores) in tissue include water, lipid, melanin, and hemoglobin. As shown in \autoref{fig:absorption_spectrum}, in biologically relevant conditions, the absorption is lowest in the near-infrared range ($\sim$600-900nm), also called the \emph{optical window}, allowing us to use light of these frequencies to investigate biological tissue. The parameter that describes the absorption of a material, as mentioned above, is $\mu_a$, the absorption coefficient. It is defined as the inverse of the average distance a photon travels in the medium before being absorbed (i.e. $\mu_a \equiv \frac{1}{l_a}$ where $l_a$ is the expected path length before encountering an absorber), typically given in units of [cm\textsuperscript{-1}]. 
\begin{figure}[tb]
    \centering
    
    \caption{Absorption spectra of various biological chromophores at concentrations typically seen in tissue. Reprinted from \cite{Scholkmann2013}, with permission from Elsevier.}
    \label{fig:absorption_spectrum}
\end{figure}

Elastic (Rayleigh and Mie) scattering is the source of the diffusive nature of light in tissue. The primary static scatterers include connective tissue, collagen, skin, as well as cellular organelles. Dynamic scattering is caused primarily by the movement of red blood cells and will be the focus of the discussion in \autoref{sec:Coherent}. It is typically ignored in the context of NIRS. The scattering coefficient $\mu_s$ summarizes the scattering properties of the material, and is defined analogously to $\mu_a$ as the inverse of the average distance a photon travels before being scattered (i.e. $\mu_s \equiv \frac{1}{l_s}$ where $l_s$ is the \emph{mean free path}), also typically presented in [cm\textsuperscript{-1}]. Scattering, however, is often not equally likely in all directions, i.e. it is not isotropic. Thus we introduce the anisotropy factor $g \equiv \expval{\cos\theta}$ (ranging from -1 to 1) as the average of the cosine of the scattering angle. For isotropic (Rayleigh) scattering, $g=0$; for total forward scattering (Mie scattering at large particles), $g=1$; for total backward scattering, $g=-1$ \cite[ch. 5.2]{Handbook}. The reduced scattering coefficient $\mu_s'$ is then defined as $\mu_s' \equiv \mu_s(1-g)$ (and similarly we have $\mu_s' \equiv \frac{1}{l^*}$ where $l^*$ is the \emph{transport mean free path}). See \autoref{fig:mfp_tmfp} for an illustration of the photon scattering behavior over these length scales. 

\begin{figure}
    \centering
    
    \caption{(a) Schematic illustration of the mean free path (MFP) $l_s=\frac{1}{\mu_s}$ and transport mean free path (TMFP) $l^*=\frac{1}{\mu_s'}$. (b) Corresponding photon distribution during light propagation for $\mu_s'=10\textnormal{cm}^{-1}$. Reprinted from \cite{Ntziachristos2010} with permission from Nature Publishing Group.}
    \label{fig:mfp_tmfp}
\end{figure}

\subsubsection{Modeling light transport}
To fully understand the interaction of light with matter, we would like to create a model of its propagation through the medium. Given measurements of light, inverting the model would then allow us to make inferences about the medium. 

One option is to run a Monte Carlo simulation. Given a three-dimensional model of the medium with known optical properties, we simulate the propagation of individual photons through the medium, using the scattering and absorption properties to probabilistically generate their trajectories, and record those that reach the detector \cite{Boas2002}. It is considered the "gold standard" for modeling, as it is valid for arbitrary three-dimensional configurations of tissue properties and source-detector positioning. The primary limitation of this method, however, is computational. To achieve statistically significant results, we must keep track of the trajectories of several million individual photons and so a single Monte Carlo simulation can take as long as several hours or even days. 

The alternative is to create a mathematical model of the light propagation in tissue. Light transport is described with the radiative transport equation (RTE), otherwise known as the Boltzmann equation, which describes the spatial and temporal distribution of radiance $L(r,t,\hat{s})$ in a volume:
\begin{multline}\label{eq:RTE}
\frac{1}{c}\frac{\partial L(r,t,\hat{s})}{\partial t} + \hat{s}\cdot\nabla L(r,t,\hat{s}) + (\mu_a + \mu_s)L(r,t,\hat{s}) \\
=\mu_s\int_{4\pi}L(r,t,\hat{s})P(\hat{s},\hat{s'})d\Omega + S(r,t,\hat{s})
\end{multline}
In the case where $\mu_s >> \mu_a$, i.e. there are many more scattering than absorption events as is typical in turbid samples such as biological tissue, we can approximate the radiative transport equation with the diffusion equation, describing the steady-state diffusion of the fluence rate $\Phi(r,t)$ through a volume:
\begin{equation}\label{eq:RTE_diffusion}
\left(-\frac{1}{3(\mu_a+\mu_s')}\nabla^2 + \mu_a\right)\Phi(r,t) = S_0(r,t)
\end{equation}
For details and a derivation, see \cite[ch. 3]{Madsen2013}. The diffusion equation can then be solved to get a closed form for $\Phi(r,t)$ for different source types (e.g. CW, FD, TD) and tissue geometries (e.g. infinite, semi-infinite, slab) \cite{Patterson1989, Farrell1992, Fantini1994, Kienle1997}. For example, for a steady-state (i.e. CW) source in a semi-infinite homogeneous medium, with a reflection geometry with source-detector separation $\rho$ (\autoref{fig:reflectance}) we can show that the fluence rate is given by
\begin{equation} \label{eq:flux_CW}
\Phi_{CW}(t) = \frac{vS_0}{4\pi D}
    \left[
        \frac{ e^{-kr_1} }{ r_1 }
       -\frac{ e^{-kr_2} }{ r_2 }
    \right]
\end{equation}
where $v$ is the speed of light in the medium, $S$ is the source intensity, and 

\begin{minipage}{0.4\textwidth}
    \centering
    \begin{align}
        &k = \sqrt{3 \mu_a \mu_s'} \\
        &r_1 = \sqrt{\rho^2+z_0^2} \label{eq:flux_vars_first}\\ 
        &r_2 = \sqrt{\rho^2+(z_0+2z_b)^2} 
    \end{align}
\end{minipage}\hspace*{\fill}%
\begin{minipage}{0.4\textwidth}
    \centering
    \begin{align}
        &D = \frac{v}{3\mu_s'} \\
        &z_0 = \frac{1}{\mu_s'}\\
        &z_b = \frac{2}{3\mu_s'}\frac{1+R_{\textnormal{eff}}}{1-R_{\textnormal{eff}}} \label{eq:flux_vars_last}
    \end{align}
\end{minipage}
\\
\\
\noindent where $\rho$ is the source detector separation. $R_{\textnormal{eff}}$ is the effective reflection coefficient and depends on the relative refractive index. It is approximately equal to 0.493 for a refractive index of $n=1.4$. For a discussion of these parameters, see \cite{Farrell1992} and references therein.

To summarize, the main underlying principle of NIRS is to measure the optical properties of the medium. Then, given models of the underlying physiology and its interaction with light, we can and make estimates about the tissue such as chromophore concentrations. 

\subsection{Continuous Wave (CW-NIRS)} \label{sec:CW-NIRS}
Continuous-wave infrared spectroscopy is the simplest of the three methods, and also the cheapest to implement due to the relatively basic instrumentation necessary \cite{Scholkmann2013}. While imaging and tomographic arrangements are now in use, along with multiplexing each channel with multiple wavelengths or even broadband (i.e. containing an entire continuous section of the spectrum) light, we describe the most basic implementation of CW-NIRS. 

A single source with two wavelengths (e.g. 690 and 830nm for measuring oxygenated and de-oxygenated hemoglobin) of light is used, typically from a pair of lasers or light emitting diodes (LEDs) delivered to the tissue through an optical fiber. Wavelengths are chosen to minimize cross-talk between chromophores as required by the Beer-Lambert Law (\autoref{eq:beer-lambert}). A single detector is used, typically in the form of a photomultiplier tube (PMT), a photodiode, or an avalanche photodiode (APD), and light is collected from the tissue and delivered to the detector through a second optical fiber. We then use the values of the incident and detected intensities for both wavelengths to calculate the concentrations of chromophores of interest -- typically, oxygenated and de-oxygenated hemoglobin.

If human tissue did not scatter light, we would be able to then use the Beer-Lambert Law (\autoref{eq:beer-lambert}) to easily calculate $\mu_a$. Measurements of the light intensity for several different wavelengths (one for each chromophore), would allow us to set up a system of equations to solve for the concentration of each chromophore using \autoref{eq:muA_sum_chromo} (extinction coefficients $\varepsilon$ have been tabulated for many compounds over many wavelengths) \cite[ch. 2]{Madsen2013}, \cite[ch. 5]{Handbook}. The reality is, however, that the scattering coefficient $\mu_s$ is several orders of magnitude larger than the absorption coefficient $\mu_a$, violating the premise of the Beer-Lambert law that the medium is non-scattering, so the theory needs to be modified accordingly. Delpy et. al. in 1988 proposed the modified Beer-Lambert Law (MBLL) as follows \cite{Delpy1988}:
\begin{equation} \label{eq:MBLL}
A \equiv -\log\frac{I}{I_0} = \mu_a\expval{\rho} + G
\end{equation}
where $\expval{\rho} = B\rho$ is the mean optical pathlength, and $B$ is called the differential pathlength factor (DPF) that accounts for the increased travel distance of a photon due to scattering. The geometry factor $G$ accounts for losses due to scattering and the measurement geometry. 

The geometry factor $G$ is typically unknown and without it we cannot calculate the absolute concentrations of chromophores. If we assume it is constant, however, we can measure the \emph{change} in concentrations by taking a baseline intensity measurement at time $t_1$ and a second one at $t_2$:
\begin{equation}
\Delta A = A_{t_2}-A_{t_1}
\end{equation}
Substituting \autoref{eq:MBLL}, we get
\begin{equation}
\Delta A = -\log\frac{I_{t_2}}{I_{t_1}} = \Delta\mu_aB\rho
\end{equation}
where the change in $\mu_a$ is due only to change in chromophore concentrations, as the extinction coefficient $\varepsilon$ is a constant property of the chromophore itself.

If we suffice with measuring the changes in chromophore concentrations, we no longer need to calculate $G$, but the differential path factor $B$ remains a problem. Based on the diffusion approximation, we can show theoretically that, for example, in a semi-infinite homogeneous medium the DPF is given by \cite{Scholkmann2013}
\begin{equation}
B = \frac{1}{2}\left( \frac{3\mu_s'}{\mu_a} \right)^{\frac{1}{2}}\left[1-\frac{1}{\sqrt{1+\rho\cdot 3\mu_a\mu_s'}}\right]
\end{equation}
This equation shows that the DPF depends on both the scattering and absorption coefficients, as well as the source-detector separation. In practice, however, it is measured empirically and assumed to be constant over time and location. Like the extinction coefficient, this value is typically tabulated and simply included in the calculation as a constant. The tabulated values themselves are measured using time-domain \cite{Chance1988, Delpy1988} or frequency-domain \cite{Franceschini1999} techniques. There are also other methods to estimate the DPF using CW light, by either making measurements using a spectrum of light rather than a set of single frequencies (known as broadband DOS), or making measurements at multiple source-detector separations (known as spatially resolved spectroscopy \cite[ch. 2.4.2]{Madsen2013}). These variations are further described in \cite{Delpy1997}. 

The primary limitation of CW-NIRS, however, is that the measured drop in intensity can be attributed to either light absorption by the tissue, or light scattering. Generally, it is due to both and we cannot separate the two effects without making an assumption about the measured medium. This issue can be addressed by measuring the change in phase of light in addition to amplitude, using frequency- or time-domain techniques. 

\subsection{Frequency Domain (FD-NIRS)}
The detailed principles of frequency-domain NIRS are not relevant for developing the theoretical description of TD-DCS, and so the discussion will be very brief, included only for completeness.

In exchange for more complicated instrumentation, FD-NIRS allows us to make exact measurements of the differential pathlength factor (DPF), avoiding the errors inherent in the estimated values used for CW-NIRS. The source intensity is modulated at radio frequency (on the order of 100MHz), such that the modulation period is shorter than the photon time of flight through the tissue. The phase shift, average intensity, and intensity oscillation of the light is measured after passing through the medium. The phase shift is then proportional to the propagation distance, providing us with a direct measurement of the DPF \cite[ch. 2]{Madsen2013}, \cite[ch. 19]{Handbook} \cite{Delpy1997}. Furthermore, given analytical solutions to the light propagating through tissue, \cite{Fantini1994, Fishkin1993}, we can estimate the optical properties of the medium \cite{Franceschini1999}. Due to the intensity modulation inherent in this technique, the light propagation model is also referred to in the literature as diffusing photon density waves (DPDW) \cite{Oleary1996thesis, Fishkin1993, Boas1996thesis,}.

\subsection{Time Domain (TD-NIRS)} \label{sec:TD-NIRS}
Time-domain near-infrared spectroscopy is a method that is equivalent to FD-NIRS in the information about tissue that it provides, though differing in the measurement principles and instrumentation, and analysis techniques. In theory, the two are related through the Fourier transform. As with CW- and FD-NIRS, there is a multitude of variations that have been implemented, so we will only describe the methodology in general terms. A more detailed review can be found in \cite{Torricelli2014} or \cite[ch. 20]{Handbook}.

In TD-NIRS, instead of using a source light that continuously illuminates the tissue, we use a short laser pulse, typically on the order of 10-100ps or less. As a result of its scattering properties, the photons then diffusely propagate through the tissue, some of them taking direct paths from the source to the detector, others traveling deeper into the tissue. Some never reach the detector due to absorption. As a result, when the pulse exits the tissue, it is delayed, attenuated, and broadened, typically several nanoseconds in temporal "width." The degree to which the pulse is affected by the tissue can then inform us about its optical properties, or the differential path factor discussed in \autoref{sec:CW-NIRS}. 

As suggested by Delpy et. al. \cite{Delpy1988}, the measured intensity profile of the pulse when it is detected is called the temporal point spread function (TPSF), since we are inputting a temporal "point" (i.e. the input laser pulse is modeled as a delta function) and are measuring how it gets spread out as a function of time. In other words, the TPSF can be considered to be the impulse response of the medium\footnote{It is worth noting that the measured TPSF is actually a convolution of the laser pulse with the "true" TPSF and the impulse response function of the detector system, so it may be necessary to remove the effects of the measurement system before analyzing the TPSF. In practice, since the pulses are of negligible width compared to the width of the tissue TPSF, this can be ignored \cite[ch. 20.4.1]{Handbook}.}.

One might assume that the photons which arrive at the detector later and therefore a longer pathlength have traveled deeper into the medium; those with a short path remain in the superficial layers. Thus, for a multi-layered medium such as the human head (\autoref{fig:reflectance_head}), if we can measure the changes in intensity of only the late photons by "time-gating" only the ones arriving within a specified period, we can measure the changes in optical properties of the deeper layers, reducing the unwanted contributions of the superficial layers. 

\begin{figure}[tb]
    \centering
    
    \caption{Illustration of a typical measurement of the brain using diffuse light. The measured volume is highlighted. Note that it includes layers of tissue that confound the measurement of the brain. Also note that the semi-infinite slab geometry that is typically used to model this setup is only an approximation of the curvature of the head. Reprinted from \cite[ch. 3]{Madsen2013}, with permission from Springer.} %© Springer Science+Business Media New York 2013}
    \label{fig:reflectance_head}
\end{figure}

One implementation of such a time-gated system was constructed in 2005 by Selb et. al. \cite{Selb2005}: the investigators used a fast electronically shuttered detector to measure the intensity during 500ps temporal gate at seven different time delays. For example, opening the shutter for 500ps with no delay measures the average intensity during the first 500ps of the TPSF. Delaying the shutter by 500ps measures the intensity in the next 500ps time block, and so forth. An analysis using the modified Beer-Lambert law similar to the one described in \autoref{sec:CW-NIRS} can then be used to infer changes in optical properties at varying depths, with early blocks corresponding to superficial layers and late blocks to deeper ones. Furthermore, the resulting measurements can be used to reconstruct the TPSF since we have a sample of the intensity at different points in the TPSF.

The more popular approach to measuring the TPSF is by a technique known as time-correlated single photon counting (TCSPC). In practice, the TPSF cannot be recorded all at once from a single pulse of light. Rather, the medium is illuminated with a train of pulses at a repetition rate on the order of 100MHz. Due to the low average power of the light, at most one photon then reaches the detector for every pulse (rather, this is an assumption made since it's impossible to guarantee due to the probabilistic nature of photon arrivals). In this setup, the only detector that is sensitive enough is either a photomultiplier tube (PMT) or single-photon avalanche photodiode (SPAD). The computer then records the time-of-flight of the photon (i.e. the length of time between the input laser pulse and the arrival of the photon) and records it in a histogram. This histogramming process is repeated until a sufficient number of photons have been accumulated to reconstruct the shape of the TPSF from the histogram. The critical principle here is that there is a greater flux of photons whenever the intensity is higher, so a photon with a time-of-flight that corresponds to the TPSF peak is far more likely to reach the detector than one with a time-of-flight corresponding to the far end of the tail. This concept is illustrated in \autoref{fig:tcspc}. A more in-depth summary of TCSPC systems can be found in \cite{Wahl2014}, and a detailed account of methods and applications in \cite{Becker2005, Becker2014}.

\begin{figure}[tb]
    \centering
    
    \caption{Conceptual illustration of time-correlated single photon counting, see text for details. Reprinted from \cite{Becker2014}.}
    \label{fig:tcspc}
\end{figure}

The TPSF can be used to determine the absolute tissue optical properties. We first derive the theoretical model of light transport for a pulse of light in terms of the optical properties using the diffusion equation as first suggested by Patterson et. al. in 1989 \cite{Patterson1989}. This gives us a prediction of the light intensity as a function of time, i.e. the TPSF. For example, for a semi-infinite medium and a reflectance geometry with a source-detector separation of $\rho$, the theoretical TPSF is given by \cite{Kienle1997} 
\begin{equation} \label{eq:TPSF}
\Phi_{TD}(t) = \frac{vS}{(4\pi D t)^{3/2}} 
\left[ 
\exp( -\frac{r_1^2} {4Dt} )
-\exp( -\frac{r_2^2} {4Dt} ) 
\right]
\exp(-v\mu_a t)
\end{equation}
where the variables are the same as in \autoref{eq:flux_CW}. This solution is obtained from \autoref{eq:RTE_diffusion} using the appropriate boundary conditions, and an impulse source (in contrast to the steady-state source used to obtain \autoref{eq:flux_CW}). 

Given the measured TPSF, we can use a fitting algorithm that tunes the relevant parameters, $\mu_a$ and $\mu_s'$ (recall that $mu_s'$ is part of the photon diffusion coefficient $D$) until we achieve the optimal agreement between the measurement and the theory. Note that the histogram amplitude depends on the measurement time, so it must be normalized for fitting. Of course, this requires the assumption that the conditions used in the theoretical derivation match the ones used in the measurement. For example, in \autoref{eq:TPSF}, we calculate the TPSF for a reflection geometry with a medium that is assumed to extend infinitely away from the light source as in \autoref{fig:reflectance}. In practice, our measurement setup more closely resembles \autoref{fig:reflectance_head}. This means when performing the measurement the tissue volume must be large enough that the boundary effects of the far edges can be neglected. Clearly, it is also assumed that photon propagation through the medium can be modeled as a diffusion process, that is $\mu_s' >> \mu_a$. 

\section{Measurement using coherent light} \label{sec:Coherent}
Note that for NIRS (\autoref{sec:NIRS}) we only rely on measurements of the average intensity of light, and make no implications about its coherence properties. As such, we use those methods to measure optical properties of the medium such as absorption and scattering. In contrast, in this section we use the coherence of light as a metric for dynamical properties of the medium such as flow and Brownian motion.

\subsection{Fundamentals: Interference and Coherence} \label{sec:fundamentals_coherence}
% https://en.wikipedia.org/wiki/Degree_of_coherence
% http://people.seas.harvard.edu/~jones/ap216/lectures/ls_3/ls3_u6A/ls3_unit6A.pdf 
% http://www.colorado.edu/physics/phys4510/phys4510_fa05/Chapter8.pdf
% Hecht Ch12

As in the previous section, we begin with a brief discussion of the basic concepts which are the workhorse of the spectroscopic techniques discussed in this section.
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

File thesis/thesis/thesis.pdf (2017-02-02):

## Time-domain diffuse correlation spectroscopy: instrument prototype, preliminary measurements, and theoretical modeling

by

## Danil Tyulmankov

S.B., EECS and BCS, MIT (2016)

Submitted to the Department of Electrical Engineering and Computer Science in partial fulfillment of the requirements for the degree of

Master of Engineering in Electrical Engineering and Computer Science

at the

MASSACHUSETTS INSTITUTE OF TECHNOLOGY

February 2017

© 2017 Danil Tyulmankov. All rights reserved.

The author hereby grants to MIT permission to reproduce and to distribute publicly paper and electronic copies of this thesis document in whole or in part in any medium now known or hereafter created.

Author |
Department of Electrical Engineering and Computer Science February 3, 2017
Certified by |
Maria Angela Franceschini
Associate Professor of Radiology, Harvard Medical School Thesis Supervisor
Certified by |
Elfar Adalsteinsson
Professor of Electrical Engineering and Computer Science, MIT Thesis Co-Supervisor
Accepted by |
Christopher Terman
Chairman, Masters of Engineering Thesis Committee

### Time-domain diffuse correlation spectroscopy: instrument prototype, preliminary measurements, and theoretical modeling

by

### Danil Tyulmankov

Submitted to the Department of Electrical Engineering and Computer Science on February 3, 2017, in partial fulfillment of the requirements for the degree of Master of Engineering in Electrical Engineering and Computer Science
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

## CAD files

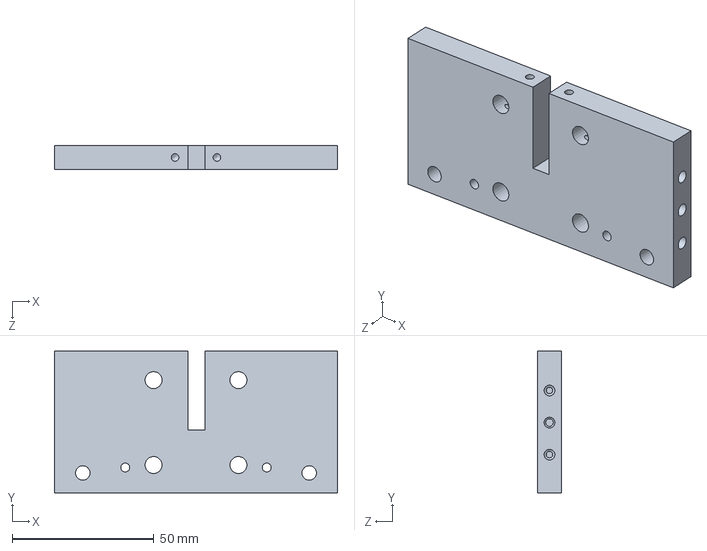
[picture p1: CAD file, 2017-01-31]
single-stage/Solidworks/LaserMountFront.SLDASM
100.0 x 50.0 x 8.50 mm

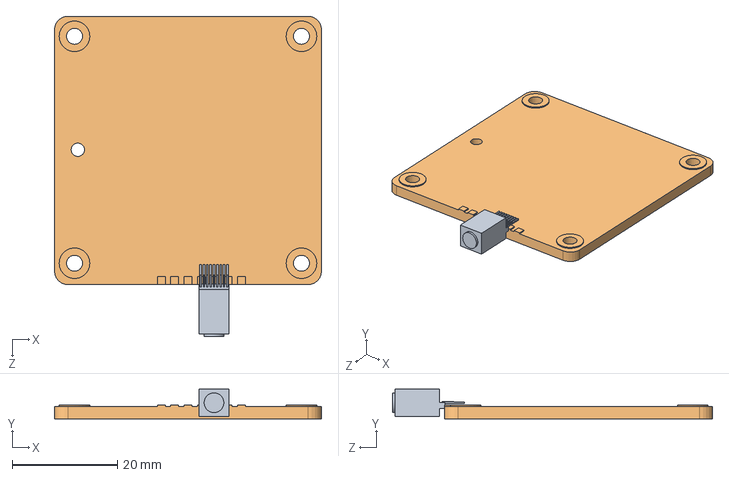
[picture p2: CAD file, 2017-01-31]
single-stage/Solidworks/Laser+PulseBoard.SLDASM
50.8 x 5.69 x 61.0 mm
laser
pulse board

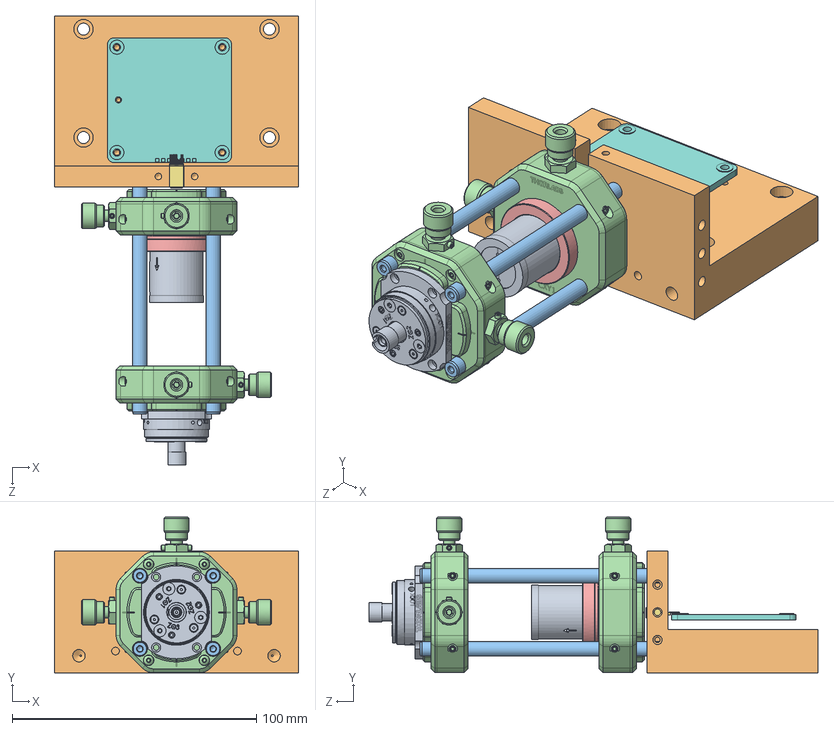
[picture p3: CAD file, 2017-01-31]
single-stage/Solidworks/Full_assembly.SLDASM
100.0 x 63.8 x 184.0 mm
IsolatorNoMount
LaserMount
Rod_ER4 x 4
XYTranslator_CXY01 x 2
Adapter-IsolatorToCagePlate_SM1B2
Adapter-LensToCagePlate_S1TM09
Laser
PulseBoard
PAF-X-15-PC-B-Solidworks

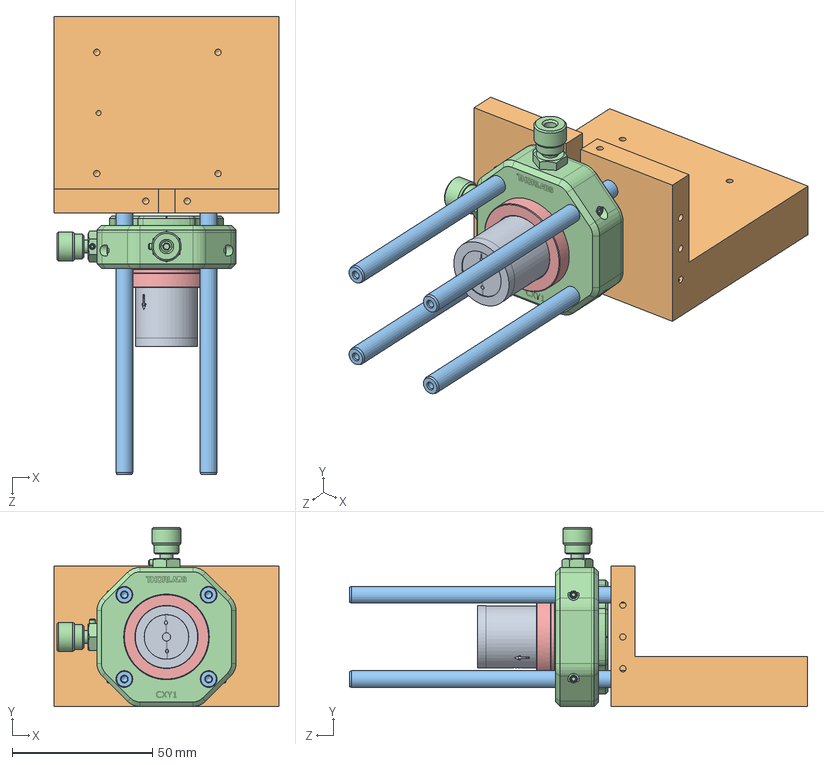
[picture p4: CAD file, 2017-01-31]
single-stage/Solidworks/LaserMount+OpticsMounts.SLDASM
80.0 x 63.8 x 163.1 mm
IsolatorNoMount
LaserMount
Rod_ER4 x 4
XYTranslator_CXY01
Adapter-IsolatorToCagePlate_SM1B2
Adapter-LensToCagePlate_S1TM09

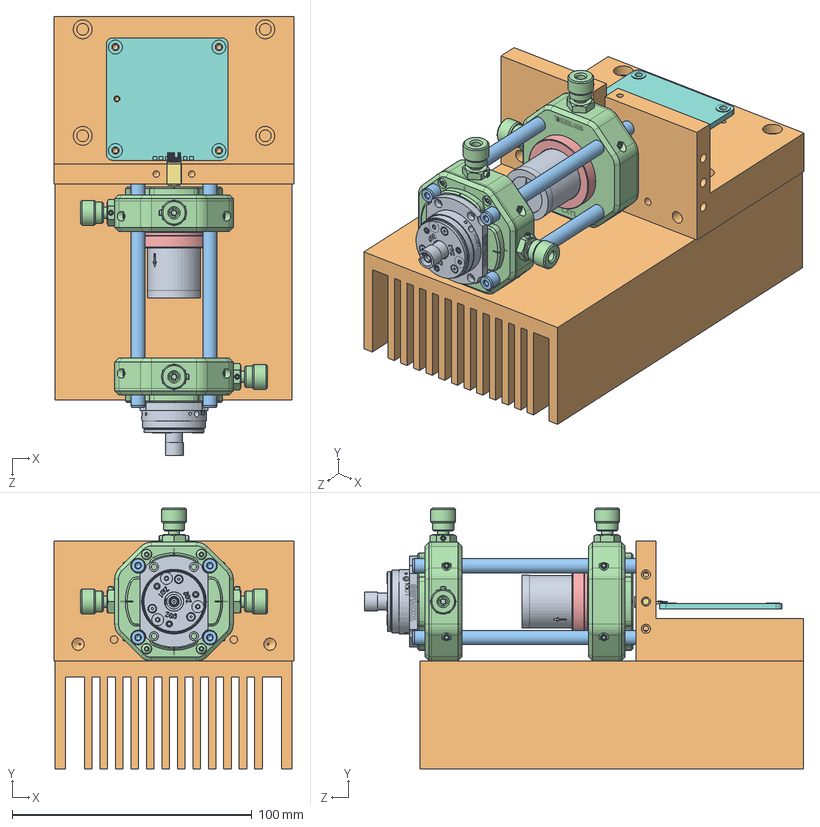
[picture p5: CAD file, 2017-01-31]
single-stage/Solidworks/LaserMount+OpticsMounts+Laser+PulseBoard.SLDASM
100.0 x 108.8 x 183.2 mm
IsolatorNoMount
LaserMount
Rod_ER4 x 4
XYTranslator_CXY01 x 2
Adapter-IsolatorToCagePlate_SM1B2
Adapter-LensToCagePlate_S1TM09
Laser
PulseBoard
PAF-X-15-PC-B-Solidworks
TE-HS-160-99MM

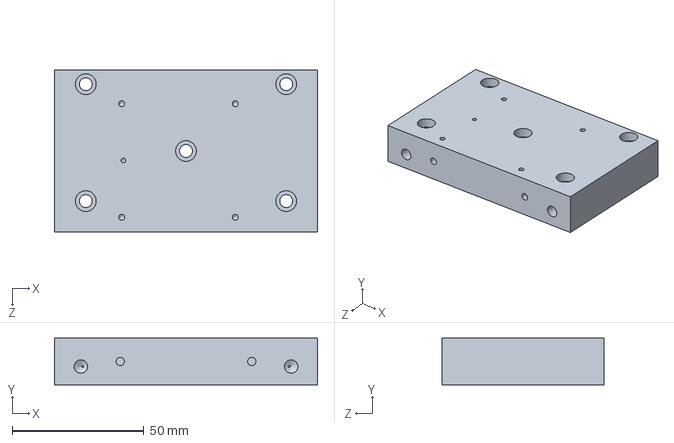
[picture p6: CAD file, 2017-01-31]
single-stage/Solidworks/LaserMountBack.SLDASM
100.0 x 17.8 x 61.5 mm

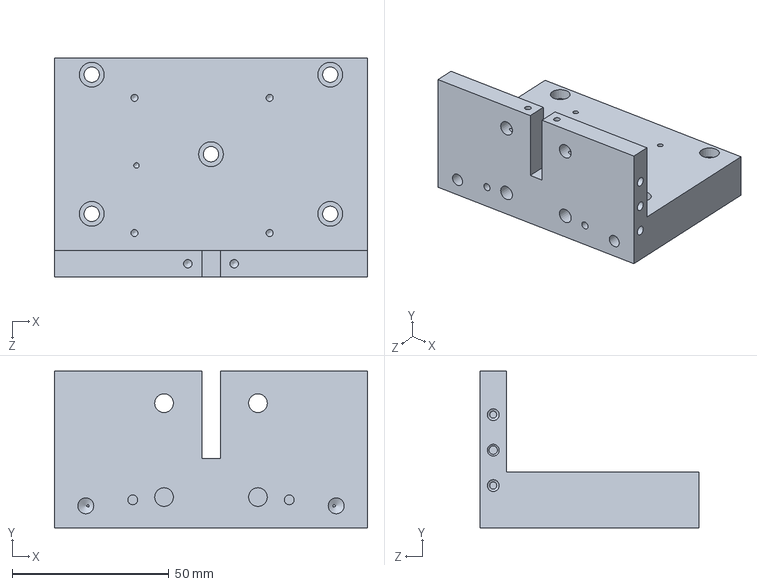
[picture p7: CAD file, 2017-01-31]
single-stage/Solidworks/LaserMount.SLDPRT
100.0 x 50.0 x 70.0 mm

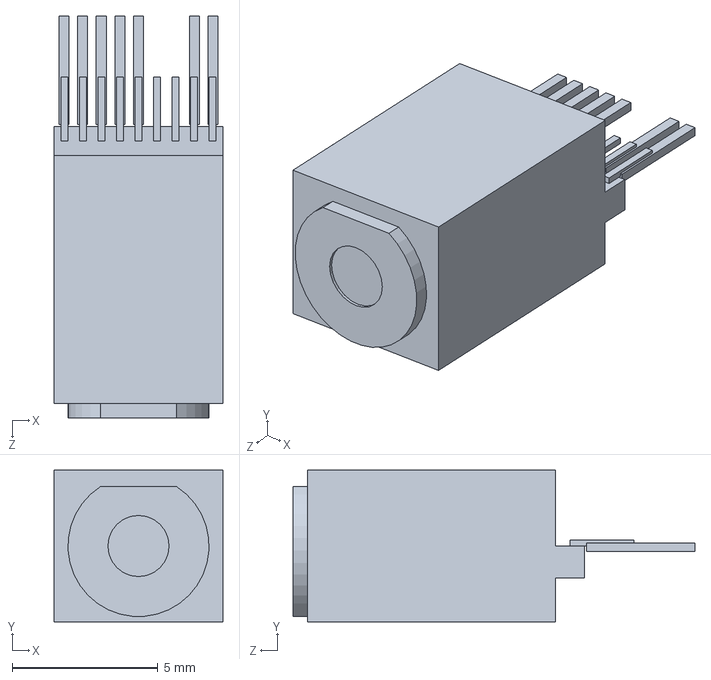
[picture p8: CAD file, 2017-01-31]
single-stage/Solidworks/Laser.SLDPRT
5.80 x 5.20 x 13.8 mm

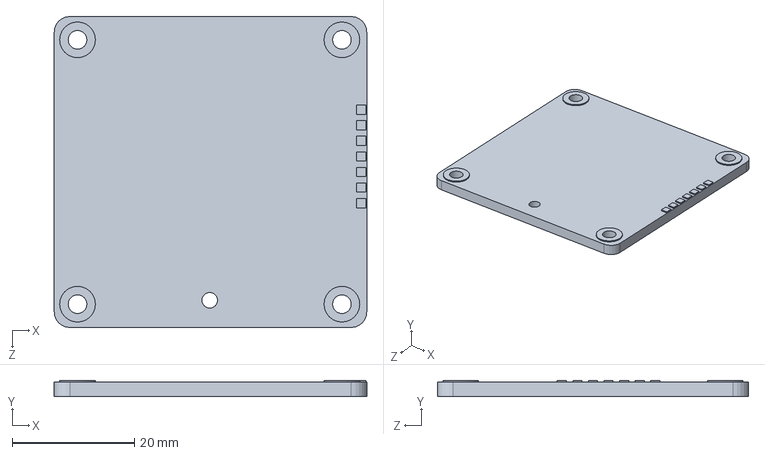
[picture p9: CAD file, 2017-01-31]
single-stage/Solidworks/PulseBoard.SLDPRT
51.1 x 2.62 x 50.8 mm

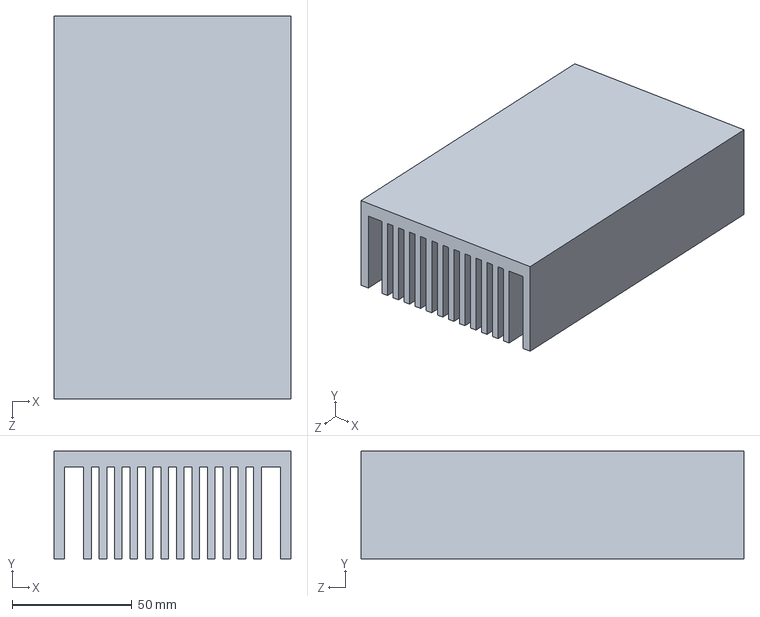
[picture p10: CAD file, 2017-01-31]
single-stage/Solidworks/TE-HS-160-99MM.SLDPRT
98.9 x 45.0 x 160.0 mm

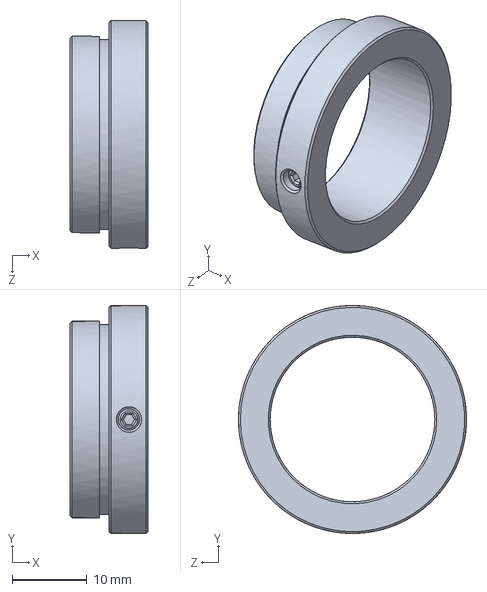
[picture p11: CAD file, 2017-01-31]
single-stage/Solidworks/Adapter-IsolatorToCagePlate_SM1B2.sldprt
10.4 x 30.5 x 30.5 mm

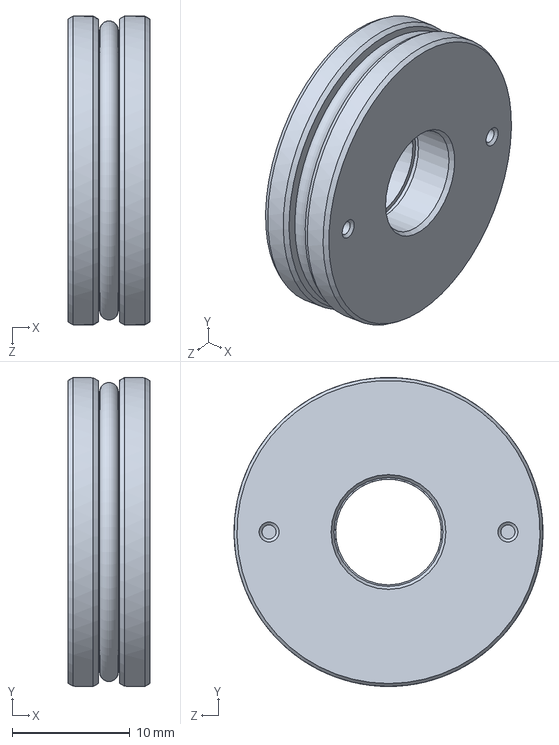
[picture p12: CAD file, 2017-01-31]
single-stage/Solidworks/Adapter-LensToCagePlate_S1TM09.sldprt
6.98 x 26.3 x 26.3 mm

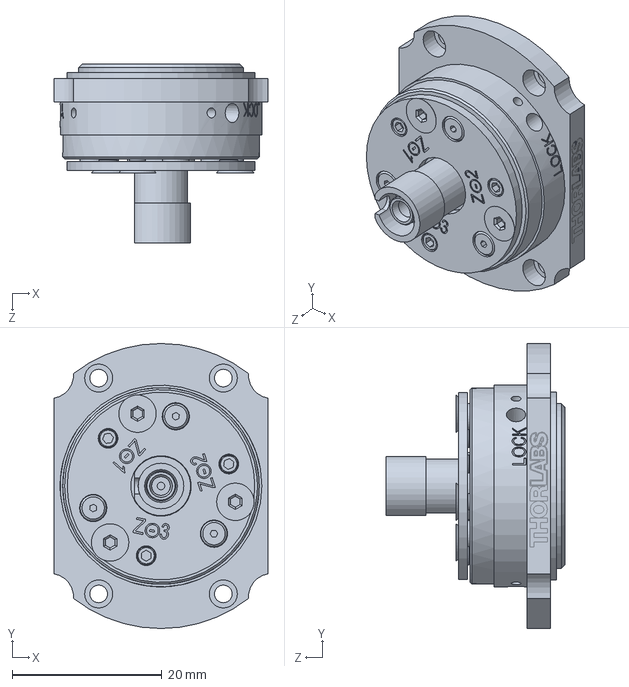
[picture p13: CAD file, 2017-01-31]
single-stage/Solidworks/PAF-X-15-PC-B-Solidworks.sldprt
28.6 x 38.1 x 24.0 mm

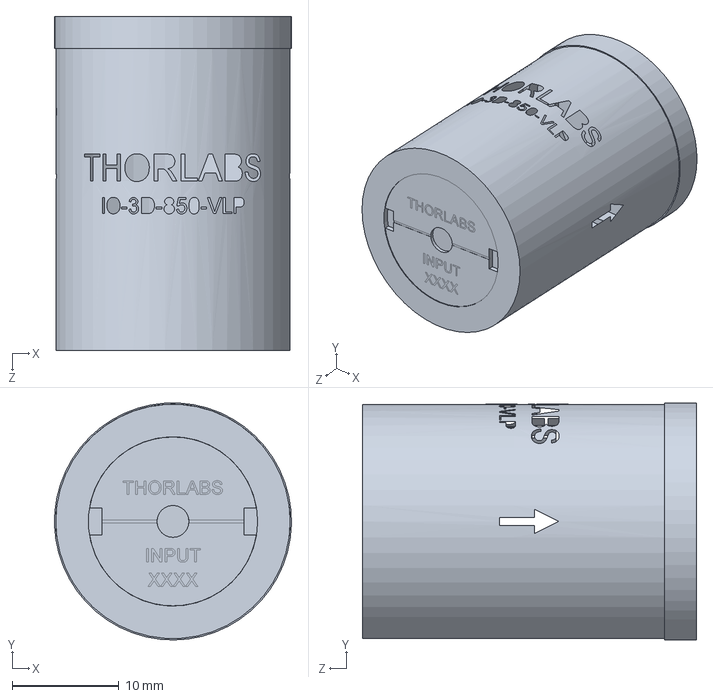
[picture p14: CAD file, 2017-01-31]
single-stage/Solidworks/IsolatorNoMount.sldprt
22.2 x 22.2 x 31.3 mm

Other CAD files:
single-stage/Solidworks/Isolator.sldprt
single-stage/Solidworks/Rod_ER4.SLDPRT
single-stage/Solidworks/CagePlate30mm_CP02.sldprt
single-stage/Solidworks/XYTranslator_CXY01.sldprt
single-stage/Solidworks/LaserMount+OpticsMounts.SLDDRW
single-stage/Solidworks/LaserMountBack.SLDDRW
single-stage/Solidworks/LaserMountFront.DXF
single-stage/Solidworks/LaserMountFront.SLDDRW
single-stage/Solidworks/LaserMountFront.SLDPRT
